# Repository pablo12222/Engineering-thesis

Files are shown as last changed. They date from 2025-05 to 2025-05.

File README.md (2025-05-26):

# Development of an electronic optimizer to control pump operation.

## Introduction

This repository contains the work and resources related to my engineering thesis titled **"Development of an electronic optimizer to control pump operation."** 

---
## Abstract 

The engineering thesis focuses on the development and construction of an electronic
(microprocessor-based) model of a setpoint controller for regulating pump performance.
The device will be implemented using a selected microcontroller with appropriately
designed input/output interfaces to interact with external devices and facilitate user
communication. The system’s operating principle can be described as follows: the
controller receives an analog 0 − 10 V signal from a regulating valve, representing the
position of the valve ball. It then compares this value with the pump’s output setpoint.
If the signal from the valve is lower than the setpoint, the device reduces the output
signal by 0.1 V at regular time intervals determined by an encoder until the target value
is reached. Conversely, if the valve ball position value exceeds the setpoint, the
controller increases the output signal by 0.1 V at the specified time intervals. The
system is equipped with three encoders for configuring operating parameters, two analog
inputs 0 − 10 V, and one analog output 0 − 10 V, ensuring precise control and
adaptation of pump performance to operational requirements. The device operates in
two modes: automatic and manual. As part of the thesis, functional tests will be
conducted using available measurement instruments and voltage generators to verify the
correct operation and compliance of the device with the design assumptions. The task is
carried out in accordance with the guidelines and for the purposes of BELIMO -
BELIMO Siłowniki S.A.

--- 

## Keywords
- transmitter,
- electronic device,
- pump control,
- microprocessor system,
- building automation.

---

## Device
This is how the developed prototype looks like:

<div style="display: flex; justify-content: center; align-items: center; gap: 10px;">
    Experimental Setup
    Experimental Result
</div>

---

## Systems hardware

Ideological diagram of the operation of the transmitter:

schemat_ideowy

---

The PCB was made with autodesk EAGLE software:


<div style="display: flex; justify-content: center; align-items: center; gap: 10px;">
    Experimental Result1
    Experimental Result2
    Experimental Result3
</div>

---

The PCB enclosure was made in Autodesk Inventor:
<div style="display: flex; justify-content: center; align-items: center; gap: 10px;">
    Experimental Result1
    Experimental Result2
    Experimental Result3
</div>

---

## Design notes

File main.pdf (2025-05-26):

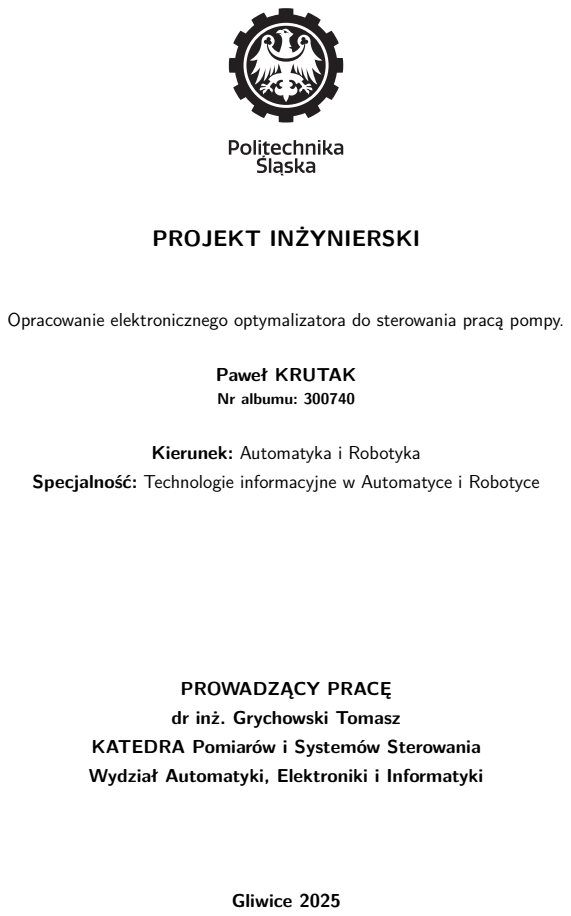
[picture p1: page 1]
PROJEKT INŻYNIERSKI; Paweł KRUTAK; Nr albumu: 300740; Gliwice 2025

Opracowanie elektronicznego optymalizatora do sterowania pracą pompy.

Kierunek: Automatyka i Robotyka

Specjalność: Technologie informacyjne w Automatyce i Robotyce

PROWADZĄCY PRACĘ
dr inż. Grychowski Tomasz

KATEDRA Pomiarów i Systemów Sterowania
Wydział Automatyki, Elektroniki i Informatyki

Opracowanie elektronicznego optymalizatora do sterowania pracą pompy.

Opracowanie elektronicznego optymalizatora do sterowania pracą pompy.

Streszczenie

Praca | inżynierska | dotyczy | opracowania | i | budowy | elektronicznego
(mikroprocesorowego) modelu zadajnika kontrolującego wydajność pompy. Urządzenie zostanie zrealizowane na bazie wybranego mikrokontrolera z zaprojektowanymi odpowiednimi interfejsami wejścia/wyjścia do współpracy z urządzeniami zewnętrznymi oraz komunikacji z użytkownikiem.
Zasadę działania systemu można opisać w następujący sposób: zadajnik odbiera sygnał analogowy 0 − 10 V z zaworu regulacyjnego reprezentujący położenie kuli zaworu. Następnie porównuje tę wartość z nastawą wyjściową pompy. W przypadku, gdy sygnał z zaworu jest mniejszy od wartości zadanej, urządzenie zmniejsza sygnał wyjściowy o 0,1 V w regularnych odstępach czasu określonych za pomocą encodera aż do osiągnięcia zadanej wartości. Analogicznie, jeśli wartość położenia kuli zaworu przekracza wartość zadaną, zadajnik zwiększa sygnał wyjściowy o 0,1 V w określonych odstępach czasu. Układ został wyposażony w trzy encodery umożliwiające konfigurację parametrów pracy, dwa wejścia analogowe 0 − 10 V oraz jedno wyjście analogowe 0 − 10 V, co zapewnia precyzyjne sterowanie i dostosowanie działania pompy do wymagań operacyjnych. Urządzenie pracuje w dwóch trybach: automatycznym oraz manualnym. W ramach pracy przeprowadzone zostaną również testy funkcjonalne z wykorzystaniem dostępnych urządzeń pomiarowych oraz zadajników napięć, mające na celu weryfikację poprawności działania i zgodności z założeniami projektowymi. Zadanie to zrealizowane jest według wytycznych i na potrzeby firmy BELIMO - BELIMO Siłowniki S.A.

Słowa kluczowe

(zadajnik, urządzenie elektroniczne, sterowanie pompą, układ mikroprocesorowy, automatyka budynkowa)

Thesis title

Development of an electronic optimizer to control pump operation.

Abstract

The engineering thesis focuses on the development and construction of an electronic (microprocessor-based) model of a setpoint controller for regulating pump performance. The device will be implemented using a selected microcontroller with appropriately designed input/output interfaces to interact with external devices and facilitate user communication. The system’s operating principle can be described as follows: the controller receives an analog 0 − 10 V signal from a regulating valve, representing the position of the valve ball. It then compares this value with the pump’s output setpoint. If the signal from the valve is lower than the setpoint, the device reduces the output signal by 0.1 V at regular time intervals determined by an encoder until the target value is reached. Conversely, if the valve ball position value exceeds the setpoint, the controller increases the output signal by 0.1 V at the specified time intervals. The system is equipped with three encoders for configuring operating parameters, two analog inputs 0 − 10 V, and one analog output 0 − 10 V, ensuring precise control and adaptation of pump performance to operational requirements. The device operates in two modes: automatic and manual. As part of the thesis, functional tests will be conducted using available measurement instruments and voltage generators to verify the correct operation and compliance of the device with the design assumptions. The task is carried out in accordance with the guidelines and for the purposes of BELIMO -BELIMO Siłowniki S.A.

Key words

(transmitter, electronic device, pump control, microprocessor system, building automation)

# Spis treści

1 Wstęp | 1
2 Opis działania zadajnika. | 4
3 Wykorzystane narzędzia pomiarowe. | 11
4 Hardware | 16

4.4.4 | Wybór Encoderów Zamiast Potencjometrów do Zadawania Wartości. 26
5 Software | 33

5.1.14 Inicjalizacja interfejsów komunikacyjnych i urządzeń peryferyjnych . 46

5.1.23 Odczyt, przetwarzanie i skalowanie napięć z pinów: VP i VN. . . . 51

6 Weryfikacja i walidacja | 57
6.2 Badanie | liniowości | przetwarzanego | napięcia | z | wejść | i | wyjścia
6.2.1 | Badanie liniowości przetwarzanego napięcia sygnału wyjściowego ze
6.2.2 | Badanie liniowości przetwarzanego napięcia sygnału z położenia kuli

6.3 Pomiary napięcia referencyjnego i rzeczywistego dla wejść zadajnika. . . . 60

6.3.2 | Pomiary napięcia referencyjnego i rzeczywistego dla wejścia z
7 Podsumowanie i wnioski | 65
Bibliografia | 68
Spis skrótów i symboli | 70
Lista dodatkowych plików, uzupełniających tekst pracy | 71
Spis rysunków | 73
Spis tabel | 74

# Rozdział 1

# Wstęp

Praca inżynierska koncentruje się na opracowaniu i budowie elektronicznego modelu zadajnika kontrolującego wydajność pompy, wykorzystującego mikrokontroler jako jednostkę obliczeniową. Celem projektu jest zbudowanie prototypu urządzenia według wytycznych i na potrzeby firmy BELIMO - BELIMO Siłowniki S.A. , który może być zastosowany do pracy z rzeczywistymi urządzeniami przemysłowymi. Kluczowym zadaniem opracowanego urządzenia jest precyzyjna regulacja parametrów pracy pompy, co pozwoli na optymalizację jej wydajności i dostosowanie do zmiennych warunków operacyjnych. Przez optymalizację rozumiemy dynamiczne dostosowanie zadajnika do zmieniających się parametrów wejściowych. Przez takie podejście uzyskujemy poprawę efektywności i wydajności pracy pompy. Niniejsza praca składa się z siedmiu rozdziałów, w których szczegółowo opisano proces projektowania, implementacji oraz testowania elektronicznego optymalizatora do sterowania pracą pompy.
Rozdział pierwszy, Wstęp, przedstawia cel projektu, znaczenie podjętego tematu oraz spodziewane korzyści wynikające z realizacji projektu. Wyjaśniono również kontekst przemysłowy, w którym może zostać zastosowany zaprojektowany zadajnik.
W rozdziale drugim, Opis działania zadajnika, omówiono: zastosowanie i uzasadnienie budowy zadajnika, przykład konkretnej instalacji, wymagania sprzętowe oraz urządzenia, z którymi zadajnik będzie współpracował. Szczegółowo zaprezentowano zasadę działania systemu, uwzględniając różne scenariusze pracy w zależności od dostępności sygnałów sterujących. Zadajnik będzie wyposażony w następujące wejścia i wyjście.
Wejścia: dwa wejścia analogowe 0 − 10 V (jedno z pompy, drugie z zaworu EV). Wyjście: jedno wyjście analogowe 0 − 10 V (do sterowania pompy).
Nastawy: encoder z wartościami od 0 do 10 V odpowiadający wartości wyjściowej. Encoder z wartościami 0 − 10 V w przypadku braku informacji z systemu zarządzania budynkiem "BMS"(ang. Building Management System), gdzie sygnał pochodzi ze sterownika PLC (ang. Programmable Logic Controller). Podsystemu automatyki budynkowej, który wypracował wyjście na podstawie stanu obiektu i przesłał je do

Paweł Krutak

urządzenia w postaci wartości analogowej w standardowym zakresie 0 − 10 V oraz encoder do ustawiania czasu. Zadajnik pobiera informacje z zaworu regulacyjnego, który wysyła sygnał analogowy 0 − 10 V, reprezentujący położenie kuli zaworu. Na podstawie tego sygnału zadajnik porównuje otrzymaną wartość z wartością wyjściową. Jeśli sygnał z zaworu jest mniejszy od wartości wyjściowej, zadajnik zmniejsza sygnał wyjściowy do pompy o 0,1 V w ustalonych odstępach czasu, aż do osiągnięcia wartości zadanej. Analogicznie, jeśli wartość położenia kuli zaworu jest większa od wyjściowej, zadajnik zwiększa sygnał wyjściowy pompy o 0,1 V w tych samych odstępach czasu. Zawór Energy Valve [5] generuje sygnał wyjściowy 0 − 10 V, który można skonfigurować do przesyłania informacji o położeniu kuli zaworu. Zadajnik precyzuje pracę pompy na podstawie stopnia otwarcia kuli zaworu, dążąc do utrzymania pożądanej pracy instalacji na podstawie wartości wejściowej. W przypadku braku sygnału z BMS (Building Management System), zadajnik wykorzystuje ustawioną wartość początkową obrotów pompy jako wartość domyślną. W sytuacji, gdy sygnał z BMS jest dostępny, zadajnik musi uwzględnić ten sygnał jako nadrzędny, co oznacza, że wszelkie inne operacje są przerywane w przypadku zmiany sygnału z BMS. Przy założeniu braku sygnału z BMS, początkowa nastawa obrotów pompy ustawiona jest na 100%. Jeśli zawór Belimo wskazuje położenie kuli na 30% (3 V), zadajnik co ustawioną przez użytkownika nastawę czasu 5, 15, 30, 45, 60 sekund zmniejsza sygnał wyjściowy do pompy o 0,1 V, dążąc do osiągnięcia 30% obrotów pompy. Proces ten trwa do momentu, aż sygnał z zaworu nie osiągnie zadanej wartości, po czym zadajnik utrzymuje odpowiednie obroty pompy, do momentu zmiany sygnału zadanego. Na końcu tego rozdziału opisana została instrukcja obsługi dla użytkownika elektornicznego optymalizatora.

Rozdział trzeci, Wykorzystane narzędzia pomiarowe, zawiera opis przyrządów używanych podczas testowania, takich jak zasilacz laboratoryjny oraz multimetry, ze szczególnym uwzględnieniem ich parametrów i zastosowania.

Rozdział czwarty, Hardware, skupia się na sprzętowej części projektu. Zawarto w nim opis komponentów wykorzystanych w zadajniku, w tym mikrokontrolera ESP32, modułu RTC, wyświetlacza OLED oraz innych elementów elektronicznych. Szczególną uwagę poświęcono projektowaniu układu elektronicznego, w tym schematu połączeń, płytki drukowanej oraz obudowy urządzenia, co pozwala na pełne zrozumienie poszczególnych etapów realizacji projektu. Dodatkowo, omówiono kompatybilność wybranych komponentów z mikrokontrolerem oraz pozostałymi elementami układu, co pozwoli na eliminację potencjalnych problemów w fazie implementacji. Rozdział czwarty dostarcza kompleksowego spojrzenia na projektowanie i implementację warstwy sprzętowej, podkreślając znaczenie synergii pomiędzy komponentami elektronicznymi a oprogramowaniem sterującym. Opisane procesy projektowe i techniczne decyzje stanowią solidną podstawę dla realizacji funkcjonalnego i niezawodnego zadajnika, odpowiadającego wymaganiom założonym na etapie planowania projektu.

Rozdział 1. Wstęp

Rozdział piąty, Software, obejmuje szczegółowy opis oprogramowania zadajnika, napisanego w języku C z wykorzystaniem środowiska Arduino IDE. Oprogramowanie stanowi kluczowy element projektu, umożliwiający pełną kontrolę nad sprzętowymi komponentami urządzenia oraz realizację jego funkcji użytkowych. Początkowo przedstawiono strukturę programu, w tym podział na moduły oraz funkcje realizujące konkretne zadania. Omówiono główne bloki kodu, takie jak inicjalizacja urządzeń peryferyjnych, obsługa wejść/wyjść cyfrowych i analogowych, a także implementacje kluczowych algorytmów sterujących. Szczególną uwagę poświęcono usprawnieniu kodu, aby zapewnić jego efektywność i zgodność z ograniczeniami zasobów mikrokontrolera. Dalsza część rozdziału zostanie poświęcona omówieniu zastosowanych bibliotek, takich jak Wire.h, U8g2lib.h, RTClib.h oraz innych, które wspierają komunikację z urządzeniami peryferyjnymi. Szczegółowo opisane zostaną sposoby wykorzystania funkcji tych bibliotek do realizacji takich zadań, jak sterowanie wyświetlaczem OLED, synchronizacja czasu z modułem RTC, czy obsługa interfejsu I²C. Wyjaśnione zostaną mechanizmy, dzięki którym biblioteki te zostały zaadaptowane do specyficznych wymagań projektu. Ponadto omówione zostaną metody obsługi zdarzeń, w tym przerwania oraz reakcje na sygnały wejściowe generowane przez przyciski. Szczególną uwagę poświęcono implementacji różnych trybów pracy urządzenia, w tym automatycznego oraz ręcznego sterowania. W końcowej części rozdziału zostaną omówione metody testowania i weryfikacji poprawności działania kodu. Opisane zostaną techniki debugowania oraz sposoby wykrywania i eliminacji potencjalnych błędów. Rozdział ten ma na celu dostarczenie pełnego obrazu procesu tworzenia i implementacji oprogramowania, które zapewnia niezawodne i efektywne działanie zadajnika.
Rozdział szósty, Weryfikacja i walidacja, prezentuje fazę testowania, podczas której zostanie sprawdzona poprawność działania zadajnika z wykorzystaniem dostępnych urządzeń pomiarowych oraz zadajników napięć. Testy te mają na celu potwierdzenie, że zadajnik działa zgodnie z założeniami i jest w stanie skutecznie zarządzać pracą pompy w różnych scenariuszach operacyjnych. W dalszych częściach pracy zostaną przedstawione szczegółowe opisy poszczególnych funkcjonalności, wyniki testów oraz analiza działania zadajnika w kontekście rzeczywistych aplikacji przemysłowych.
Ostatni rozdział, Podsumowanie i wnioski, podsumowuje efekty pracy, ocenia stopień realizacji założonych celów oraz wskazuje potencjalne kierunki rozwoju projektu.

# Rozdział 2

Opis działania zadajnika.

Współczesne systemy automatyzacji wymagają coraz bardziej zaawansowanych narzędzi umożliwiających precyzyjne sterowanie pracą urządzeń, w tym pomp
wykorzystywanych | w | różnorodnych | instalacjach | przemysłowych, | budynkowych
i technologicznych. Zadania te obejmują dynamiczne dostosowywanie parametrów pracy do zmieniających się warunków operacyjnych oraz potrzeb użytkowników.
Rozdział drugi pracy inżynierskiej koncentruje się na szczegółowym opisie działania projektowanego zadajnika, jego funkcjonalności oraz współpracy z elementami systemu. Zadania realizowane przez zadajnik obejmują precyzyjną regulację pracy pompy w instalacjach technicznych, takich jak systemy HVAC, budynki komercyjne, instalacje przemysłowe oraz systemy chłodzenia serwerowni.
W kolejnych podrozdziałach przedstawiono szerokie zastosowania zadajnika, a także omówiono przykłady konkretnych instalacji, w których może być on wykorzystany.
Zaprezentowano | także | szczegółowe | wymagania | sprzętowe, | opis | urządzeń
współpracujących z zadajnikiem oraz dokładny opis zasad jego działania.

2.1 Zastosowania i uzasadnienie budowy zadajnika.

Projektowany zadajnik znajduje szerokie zastosowanie w systemach automatyzacji, które wymagają precyzyjnego sterowania pracą pomp oraz usprawnienia przepływu medium. Przykłady takich instalacji obejmują:

- Systemy HVAC (Heating, Ventilation, Air Conditioning): Zadaniem zadajnika w takich systemach jest dynamiczne dostosowanie pracy pomp obiegowych do aktualnych warunków eksploatacyjnych, takich jak zmienne zapotrzebowanie na ciepło lub chłód. Dzięki precyzyjnej regulacji przepływu medium możliwe jest zwiększenie efektywności energetycznej całego systemu, co prowadzi do obniżenia kosztów eksploatacji oraz zmniejszenia emisji CO2.
- Budynki komercyjne i użyteczności publicznej: W dużych budynkach,

Rozdział 2. Opis działania zadajnika.

takich jak biurowce, hotele czy szpitale, utrzymanie stabilnych parametrów pracy układów cyrkulacyjnych jest kluczowe dla komfortu użytkowników oraz wydajności systemu. Zadania realizowane przez zadajnik, takie jak dostosowanie prędkości pomp do sygnałów wejściowych z systemu zarządzania budynkiem (BMS), zapewniają niezawodność i efektywność instalacji.

- Instalacje | przemysłowe: | W | procesach | technologicznych | wymagających
precyzyjnej regulacji przepływu medium, np. w układach chłodzenia maszyn lub urządzeń, zadajnik umożliwia sterowanie pracą pompy, co przekłada się na większą kontrolę nad procesami oraz oszczędności energetyczne.
- Systemy chłodzenia serwerowni: W serwerowniach precyzyjne sterowanie temperaturą jest kluczowe dla zapewnienia ciągłości pracy sprzętu. Zadajnik umożliwia regulację przepływu medium chłodzącego w zależności od obciążenia systemu, co pozwala na efektywne zarządzanie temperaturą.

Głównym celem projektu zadajnika jest zwiększenie efektywności i elastyczności zarządzania pracą pomp w różnych instalacjach. Współczesne systemy HVAC oraz instalacje przemysłowe wymagają coraz bardziej zaawansowanych metod regulacji, które pozwalają na dynamiczne dostosowywanie parametrów pracy do zmieniających się warunków.

2.1.1 Przykład konkretnej instalacji.

Projektowany zadajnik może być zastosowany w instalacji grzewczej nowoczesnego budynku biurowego, w którym system HVAC (ogrzewanie, wentylacja i klimatyzacja) wykorzystuje pompy obiegowe do cyrkulacji medium grzewczego.
W tej instalacji zastosowano:
- Pompy obiegowe Wilo-Yonos ECO 25/1-5, sterowane napięciem 0 − 10 V, które dynamicznie dostosowują prędkość przepływu wody w zależności od zapotrzebowania na ciepło w różnych strefach budynku.
- Zawory Belimo Energy Valve™, które monitorują i kontrolują przepływ medium oraz przekazują sygnały o położeniu kuli zaworu (stopnia otwarcia). Położenie kuli zaworu jest kluczowym parametrem, który pozwala na precyzyjne określenie bieżącego zapotrzebowania na przepływ medium w danej strefie budynku.
- System zarządzania budynkiem (BMS), który zbiera dane o zapotrzebowaniu na energię cieplną w poszczególnych strefach obiektu i przesyła je do zadajnika jako sygnały wejściowe.

Paweł Krutak

W praktyce zadajniki odczytują sygnały z zaworu regulacyjnego oraz z systemu BMS. Na podstawie informacji o położeniu kuli zaworu oraz sygnału z BMS, zadajniki dynamicznie regulują prędkość obrotową pomp. Dzięki temu każda strefa budynku otrzymuje dokładnie tyle energii cieplnej, ile potrzebuje, co minimalizuje straty energetyczne i obniża koszty eksploatacji.

Przykład zastosowania: W budynku o powierzchni 10 000 m², podzielonym na kilka stref grzewczych (np. biura, sale konferencyjne, pomieszczenia techniczne), zadajniki umożliwiają regulację pracy pomp w taki sposób, aby dopasować przepływ medium grzewczego do zapotrzebowania każdej strefy. Na przykład:

- W godzinach pracy biur (8:00–18:00) system, bazując na informacji o położeniu kuli zaworu, zwiększa przepływ medium do stref intensywnie użytkowanych.
- W godzinach nocnych system BMS, przy wsparciu zadajnika, redukuje przepływ do minimalnego poziomu, pozwalając jedynie na utrzymanie temperatury ochronnej (np. 15°C).

Dzięki wykorzystaniu informacji o położeniu kuli zaworu oraz sygnałów z systemu BMS, takie rozwiązanie pozwala na wydajniejszą pracę systemu grzewczego, zmniejszenie zużycia energii o 20–30% oraz zwiększenie komfortu użytkowników budynku.

2.2 Wymagania sprzętowe do projektu.

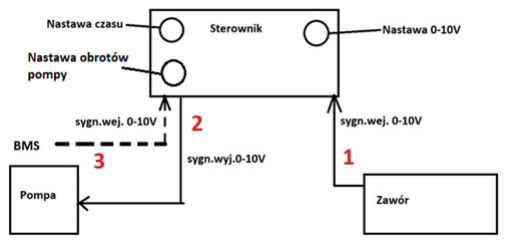
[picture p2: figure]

Rysunek 2.1: Ideowy schemat działania zadajnika (rysunek od "zleceniodawcy").

Zaprojektowany zadajnik ma wykorzystywać mikrokontroler jako centralną jednostkę obliczeniową, która ma odczytywać wejścia i w odpowiedni sposób wysterowywać
wyjścia. | Na | rysunku | 2.1 | przedstawiono | ideowy | schemat | działania | układu.
Mikrokontroler odczytuje sygnały analogowe z zakresu 0 − 10 V. Jeden z nich przekazuje

Rozdział 2. Opis działania zadajnika.

informacje o położeniu kuli zaworu EV, a drugi dostarcza dane o prędkości obrotowej silnika pompy - sygnał z systemu zarządzania budynkiem "BMS"(ang. Building Management System). Wyjście przekazuje sygnał ciągły 0 − 10 V, który steruje pompą. Na rysunku 2.1 przedstawiono trzy encodery umożliwiające ustalenie nastaw. Pierwszy z nich to nastawa czasu, w którym użytkownik może wybrać wartości z przedziału 5, 15, 30, 45, 60 sekund. Drugi encoder jest do ustawienia obrotów pompy w przypadku braku sygnału wejściowego z BMS’u - nastawa wartości 0 − 10 V z krokiem 0.1 V. Ostatni z kolei ma działać tak samo jak drugi encoder, ale służy do ustawienia wartości wyjściowej do sterowania pompą.

## 2.3 Opis urządzeń do których zadajnik ma zostać

podpięty.

### Pompa obiegowa Wilo-Yonos ECO 25/1-5 BMS z sygnałem 0-

10V.

Rysunek 2.2: Opis sygnałów i wyprowadzeń pompy obiegowej Wilo-Yonos ECO 25 [22].

Pompa | obiegowa | Wilo-Yonos | ECO | 25/1-5 | to | wydajne | urządzenie
wykorzystywane w systemach grzewczych i chłodniczych, które pracuje w zakresie napięcia sterującego 0 − 10 V. Posiada zdolność dostosowywania swoich obrotów w zależności od sygnału sterującego, co pozwala na polepszenie pracy całego systemu. Sygnał sterujący można przesyłać do pompy za pomocą dedykowanego wejścia - rysunek 2.2, co umożliwia jej integrację z systemami automatyki budynkowej. Masa sygnału (GND) oraz zasilanie pompy muszą być poprawnie podłączone, aby zapewnić właściwą komunikację i stabilną pracę urządzenia [22].
Sygnał 0 − 10 V w technologii automatyki budynkowej (Building Management System, BMS) jest standardowym sygnałem analogowym, powszechnie stosowanym w systemach automatyki przemysłowej i budynkowej. W praktyce sygnał ten może być generowany przez sterownik PLC (ang. Programmable Logic Controller) będący częścią podsystemu automatyki budynkowej. Sterownik, na podstawie analizy stanu obiektu (np. odczytu temperatury, przepływu czy zapotrzebowania na energię cieplną), generuje sygnał wyjściowy i przesyła go do naszego urządzenia w postaci standardowego sygnału

Paweł Krutak

analogowego 0 − 10 V. Taki sygnał może być wykorzystany do sterowania parametrami pracy urządzeń, takimi jak prędkość obrotowa pompy czy przepływ medium. Dzięki temu możliwe jest precyzyjne zarządzanie systemami grzewczymi i chłodniczymi, co prowadzi do zwiększenia efektywności energetycznej oraz redukcji kosztów eksploatacji.

Zawór Belimo Energy Valve™.

Zawór Belimo Energy Valve™ to zaawansowane urządzenie służące do zarządzania przepływem medium w systemach HVAC. Jest wyposażony w interfejs sygnału 0 − 10 V co umożliwia monitorowanie i kontrolę położenia kuli zaworu (stopnia otwarcia). Funkcjonalność ta pozwala na precyzyjne sterowanie wydajnością instalacji, zwiększając jej efektywność. Energy Valve (EV) pozwala także na wybór rodzaju przesyłanej informacji. Jednym z najistotniejszych parametrów jest pozycja kuli zaworu, która może służyć za podstawę do regulacji pracy pompy. Informację o położeniu kuli zaworu otrzymujemy z pomarańczowego oraz białego przewodu przedstawionego na rysunku 2.3, Urządzenie wspiera działania usprawniające, dzięki czemu możliwe jest utrzymywanie odpowiednich parametrów instalacji przy minimalnym zużyciu energii [5].

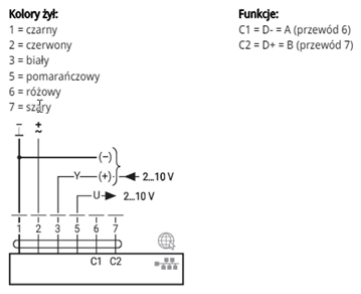
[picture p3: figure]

Rysunek 2.3: Wyprowadzenia sygnałów z zaworu Belimo Energy Valve™ [5].

2.4 Dokładny opis działania systemu.

System sterowania pompą na podstawie informacji z zaworu oparty jest na mikrokontrolerze ESP32 i umożliwia dynamiczne dostosowywanie pracy instalacji w zależności od aktualnych warunków oraz preferencji użytkownika. Główne zadanie

Rozdział 2. Opis działania zadajnika.

systemu polega na regulacji prędkości pompy na podstawie sygnałów napięciowych 0 − 10 V pochodzących z zaworu regulacyjnego i systemu zarządzania budynkiem (BMS). System działa w dwóch trybach: automatycznym i manualnym. W trybie automatycznym zadajnik analizuje sygnał z położenia kuli zaworu (EV), porównując go z aktualną wartością wyjściową co ustawiony interwał czasowy, na przykład 8 V to odpowiada 80% otwarcia zaworu. Przez użytkownika określany jest interwał czasowy, ustawiony za pomocą encodera z przedziału 5, 15, 30, 45, 60 sekund. Zadajnik dostosowuje napięcie wyjściowe dla pompy, zwiększając lub zmniejszając je o 0,1 V, aby osiągnąć zadany poziom. W przypadku dostępności sygnału z BMS system bezpośrednio przekazując wartość sterującą z BMS do pompy. Tryb manualny pozwala użytkownikowi na bezpośrednie ustawienie napięcia wyjściowego za pomocą enkodera, umożliwiając pełną kontrolę nad pracą pompy. Interfejs użytkownika obejmuje wyświetlacz OLED, na którym prezentowane są informacje o aktualnym czasie, trybie pracy, trybie pracy BMS (w przypadku braku wartości wejściowej z BMS użytkownik może zmienić tryb i ustawić priorytetową wartość za pomocą enkodera), wartości wejściowych z EV i BMS, napięciu wyjściowym dla pompy oraz aktualnych nastawach. Dodatkowo diody LED sygnalizują aktywność pompy, stan zaworu oraz obecność sygnału z BMS. W przypadku braku sygnału wejściowego z BMS w chwili startu zadajnik startuje z wartości wyjściowej dla pompy równej 10 V.

2.5 | Instrukacja | obsługi | elektronicznego
| optymalizatora.

Elektroniczny optymalizator jest urządzeniem przeznaczonym do precyzyjnej regulacji pracy pomp w systemach HVAC oraz innych instalacjach wymagających dynamicznego sterowania przepływem medium. Aby rozpocząć pracę, należy podłączyć urządzenie do źródła zasilania 12 V oraz upewnić się, że sygnały z zaworu regulacyjnego EV i systemu BMS są poprawnie podłączone do dedykowanych wejść. Po uruchomieniu urządzenia domyślnie aktywowany jest tryb automatyczny, w którym elektroniczny optymalizator analizuje sygnały napięciowe 0 − 10 V z wejść i dostosowuje napięcie wyjściowe sterujące pompą. Interwał czasowy regulacji można ustawić za pomocą obrotowego encodera, wybierając wartość z przedziału {5, 15, 30, 45, 60} sekund, a wybrany interwał jest prezentowany na wyświetlaczu OLED.

W trybie automatycznym optymalizator priorytetowo wykorzystuje sygnał z systemu BMS, o ile jest dostępny, przekazując bezpośrednio wartość sterującą do pompy. W przypadku braku sygnału z BMS regulacja odbywa się na podstawie pozycji kuli zaworu EV, którą urządzenie porównuje z aktualnym napięciem wyjściowym i koryguje o 0.1 V co zadany interwał czasowy. Istnieje jednak możliwość zmiany źródła wartości

Paweł Krutak

wejściowej w przypadku braku sygnału z BMS. Użytkownik może przełączyć tryb wejściowy na wartość zadaną za pomocą encodera nastawy BMS. W tym trybie encoder pełni funkcję ustawienia priorytetowej wartości, która będzie wykorzystywana do sterowania pompą. Przełączanie trybu źródła sygnału odbywa się za pomocą wbudowanego przycisku encodera.
W trybie manualnym użytkownik może ręcznie ustawić napięcie wyjściowe za pomocą encodera, a jego wartość jest na bieżąco wyświetlana na ekranie OLED. Interfejs użytkownika dostarcza kluczowych informacji o stanie systemu, w tym aktualnego czasu, trybu pracy (automatyczny/manualny), napięć z wejść EV i BMS, napięcia wyjściowego oraz źródła danych wejściowych (BMS_WE lub BMS_ENC). Dodatkowo diody LED sygnalizują aktywność napięcia wyjściowego, obecność sygnału z BMS oraz sygnału z zaworu EV, co umożliwia szybkie monitorowanie stanu urządzenia. W przypadku braku sygnału z BMS podczas uruchamiania systemu, optymalizator rozpoczyna pracę z maksymalnym napięciem wyjściowym 10 V, co zapewnia pełną moc pompy do czasu ustabilizowania parametrów. Regularne odczyty i przetwarzanie sygnałów są realizowane w sposób ciągły, co gwarantuje płynną pracę urządzenia oraz wysoką precyzję regulacji. W razie problemów, takich jak brak wyświetlania na OLED, nieaktywne diody lub nieprawidłowe działanie encodera, należy sprawdzić poprawność połączeń, wartości sygnałów wejściowych oraz stan techniczny podzespołów.

# Rozdział 3

Wykorzystane narzędzia pomiarowe.

Celem niniejszego rozdziału jest przedstawienie narzędzi pomiarowych, które zostały wykorzystane w trakcie realizacji projektu, zarówno podczas pisania oprogramowania dla mikrokontrolera, jak i w procesie badania liniowości zaprojektowanego układu. Opisano tutaj urządzenia, które umożliwiły precyzyjne pomiary kluczowych parametrów systemu, takich jak napięcia, rezystancje oraz inne właściwości elektryczne.

Przeprowadzenie precyzyjnych pomiarów oraz analiza uzyskanych wyników stanowiły kluczowy element weryfikacji poprawności działania zaprojektowanego zadajnika oraz oceny zgodności jego parametrów z założeniami projektowymi. W rozdziale omówiono zasilacz laboratoryjny, który służył jako symulator sygnałów wejściowych, oraz dwa multimetry cyfrowe, wykorzystywane do precyzyjnych pomiarów napięć i rezystancji.

Przedstawienie parametrów technicznych i zakresów działania użytych narzędzi pozwala podkreślić ich rolę w procesie projektowania i testowania układu sterowania, a także zapewnia wiarygodność uzyskanych wyników.

3.1 Zasilacz laboratoryjny.

Zasilacz laboratoryjny DF173005C [13], przedstawiony na rysunku 3.1, to
wszechstronne | urządzenie | przeznaczone | do | precyzyjnego | zasilania | układów
elektronicznych. Znajduje zastosowanie w laboratoriach, pracach serwisowych oraz procesach prototypowania.

### Dokładność napięcia

Dokładność napięcia wyjściowego zasilacza wynosi:

±(1% wartości ustawionej + 2 cyfry),

Paweł Krutak

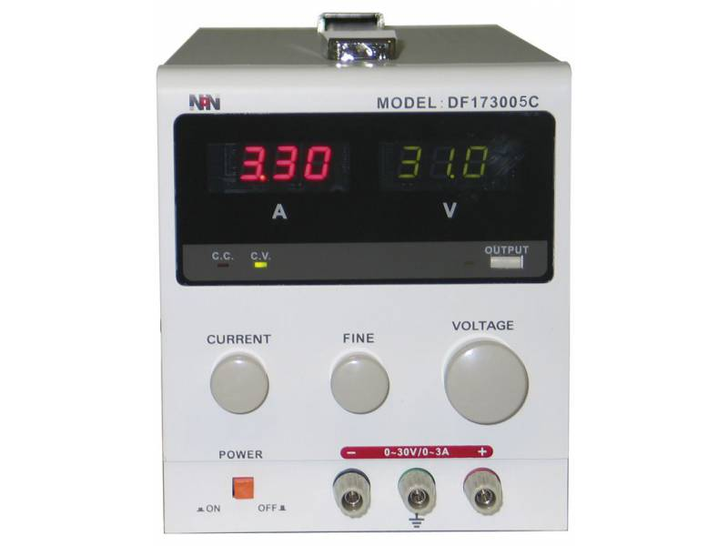
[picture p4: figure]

Rysunek 3.1: Zasilacz laboratoryjny DF173005C NDN – 30V, 5A. Zdjęcie ze strony sklepu ndn.com.pl [13].

co gwarantuje stabilne i precyzyjne zasilanie układów wymagających pewnej dokładności [13].

### Zakres pracy

Zasilacz umożliwia regulację napięcia w zakresie od 0 V do 30 V, z minimalnym tętnieniem wynoszącym ≤ 1 mVrms (dla zakresu częstotliwości od 5 Hz do 1 MHz). Tętnienia i szumy są minimalne, co zapewnia stabilność napięcia wyjściowego, szczególnie w układach czułych na zakłócenia [13].

Zastosowanie zasilacza w projekcie.

Zasilacz DF173005C został wykorzystany w projekcie jako źródło symulowanych sygnałów wejściowych, reprezentujących informacje o położeniu kuli zaworu EV oraz wartości sygnału BMS w zakresie 0 − 10 V oraz dla wejścia sygnału z BMS’u, który też pracuje w tym zakresie.

## 3.2 Wykorzystane multimetry:

Wykorzystane w projekcie multimetry służyły do pomiarów takich jak: pomiar rezystancji rezystorów, sprawdzenie liniowości dzielnika napięcia dla dobranych rezystorów, badanie liniowości wzmacniacza operacyjnego dla obliczonych parametrów, sprawdzenie liniowości dla wejść układu oraz badanie liniowości wyjścia zadajnika.

Rozdział 3. Wykorzystane narzędzia pomiarowe.

### 3.2.1 Multimetr Sonel

Multimetr cyfrowy Sonel CMM-10 [12], przedstawiony na rysunku 3.2, to zaawansowane narzędzie pomiarowe, umożliwiające precyzyjne pomiary napięcia stałego
oraz | rezystancji. | Jego | wszechstronność | sprawia, | że | znajduje | zastosowanie
w różnorodnych pracach laboratoryjnych i inżynierskich.

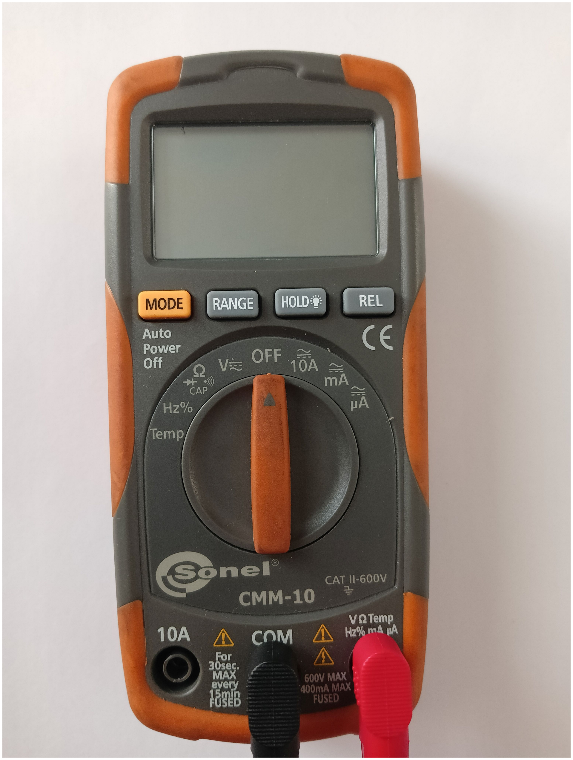
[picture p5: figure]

Rysunek 3.2: Multimetr Sonel CMM-10.

Multimetr w projekcie był wykorzystywany jako woltomierz do pomiaru wartości napięcia prądu stałego, oraz omomierz - pomiar rezystancji. Poniżej znajduje się opis dokładności miernika dla pomiaru tych dwóch wartości.

Pomiar napięcia stałego (DC)

Multimetr oferuje zakres pomiaru napięcia stałego do 600 V z dokładnością wynoszącą:

±(0, 5% wartości mierzonej + 2 cyfry).

Rozdzielczość pomiaru wynosi od 0,1 mV, co umożliwia dokładne analizy w szerokim zakresie pomiarowym [12].

Paweł Krutak

### Pomiar rezystancji

Urządzenie pozwala na pomiar rezystancji do 40,00 MW z dokładnością:

±(1, 0% wartości mierzonej + 2 cyfry).

Rozdzielczość wynosi od 0,1 W, co zapewnia precyzyjne wyniki nawet w przypadku dużych wartości rezystancji [12].

Multimetr NEO.

Multimetr cyfrowy NEO 94-001 [18] pokazany na rysunku 3.3, został wykorzystany w projekcie wyłącznie do pomiarów napięcia prądu stałego. Dlatego poniżej zostały opisane dane dotyczące zakresów, rozdzielczości oraz dokładności, jedynie dla woltomierza prądu stałego.

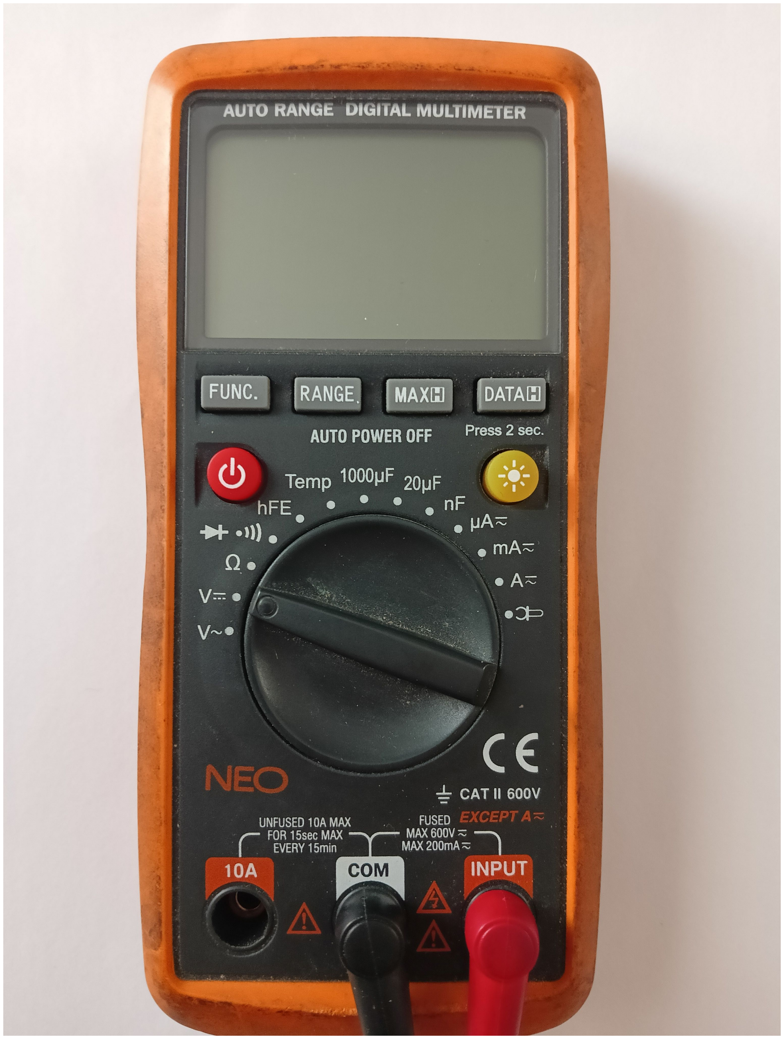
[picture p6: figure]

Rysunek 3.3: Multimetr NEO 94-001.

Zakresy pomiarowe [18]

- 200 mV z rozdzielczością 0,1 mV,
- 2 V z rozdzielczością 0,001 V,
- 20 V z rozdzielczością 0,01 V,
- 200 V z rozdzielczością 0,1 V,

Rozdział 3. Wykorzystane narzędzia pomiarowe.

- 600 V z rozdzielczością 1 V.

Dokładność pomiarów [18]

- ±(0, 8% wartości mierzonej + 5 cyfr) dla zakresów do 200 V,
- ±(1, 0% wartości mierzonej + 5 cyfr) dla zakresu 600 V.

Impedancja wejściowa

Multimetr charakteryzuje się wysoką impedancją wejściową wynoszącą 10 MΩ, co minimalizuje wpływ miernika na badany obwód [18].

# Rozdział 4

# Hardware

W niniejszym rozdziale przedstawiono szczegółowy opis komponentów sprzętowych wykorzystanych w projekcie, proces projektowania płytki drukowanej (PCB) oraz wykonania obudowy urządzenia. Celem rozdziału jest przedstawienie kluczowych decyzji projektowych, które zadecydowały o funkcjonalności i niezawodności systemu sterowania pompą obiegów.
Omówione zostaną najważniejsze elementy układu, takie jak mikrokontroler ESP32, moduł czasu rzeczywistego RTC DS1307, wzmacniacz operacyjny LM358P oraz przetwornica DC-DC MP2315, wraz z uzasadnieniem ich wyboru oraz opisem ich roli w projekcie. Ponadto, szczególną uwagę poświęcono opisowi układów wspomagających, takich jak rezystory, kondensatory oraz encodery obrotowe, które umożliwiają
precyzyjne | przetwarzanie | sygnałów | wejściowych | i | sterowanie | urządzeniami
wykonawczymi.
Dalsza część rozdziału skupia się na procesie projektowania płytki PCB, który obejmował rozmieszczenie komponentów, dobór odpowiednich szerokości ścieżek. W ostatniej części rozdziału zaprezentowano projekt obudowy, której konstrukcja
została | dostosowana | do | specyfikacji | technicznych | urządzenia | i | wykonana
z wykorzystaniem technologii druku 3D. Szczegółowe omówienie tych aspektów pozwala na pełne zrozumienie procesu tworzenia sprzętu oraz jego integracji z oprogramowaniem, co jest kluczowe dla osiągnięcia założonej funkcjonalności systemu.

## 4.1 Schemat połączeń

Przy projektowaniu układu kluczowym krokiem było stworzenie szczegółowego schematu połączeń, który stanowił podstawę do zamówienia potrzebnych elementów, zaprojektowania płytki PCB oraz zaplanowania montażu. Poniższy rysunek 4.1 prezentuje schemat połączeń komponentów zadajnika zaprojektowany w programie EAGLE firmy Autodesk [4].

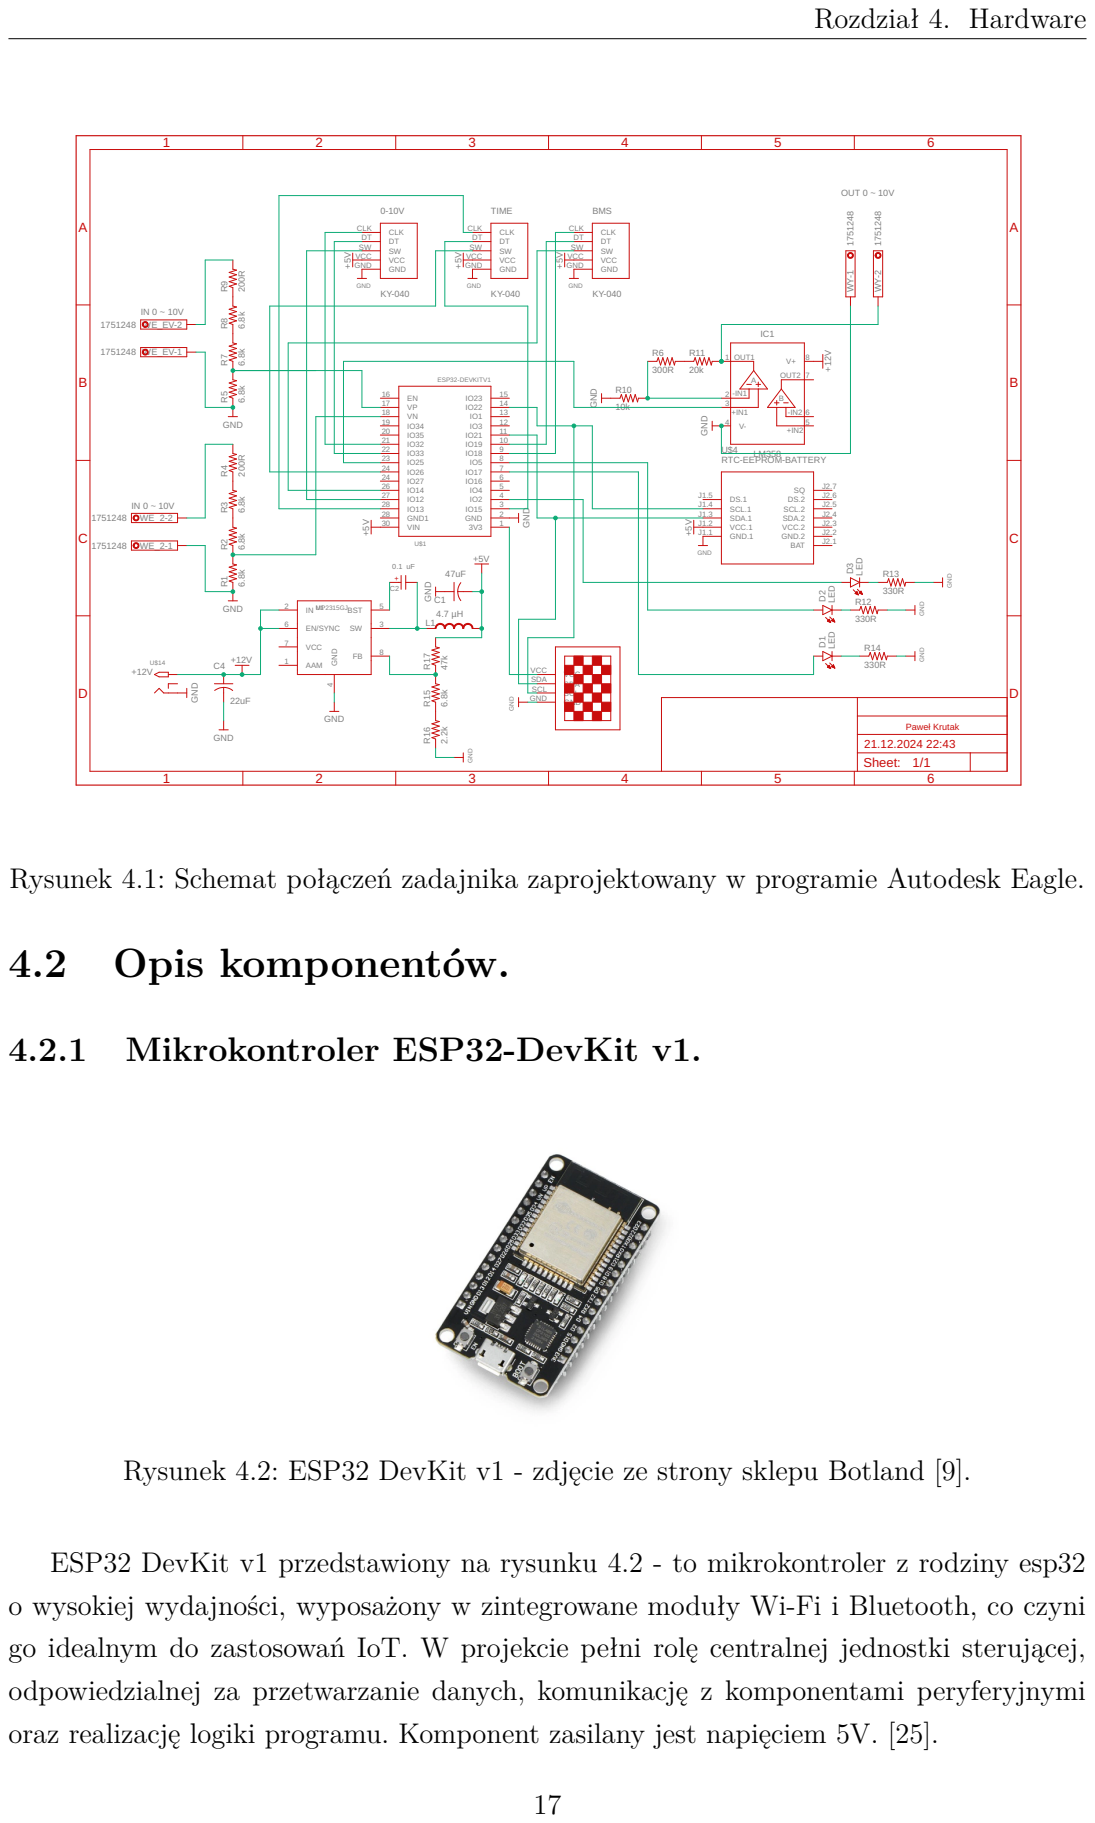
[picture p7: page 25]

OUT 0 ~ 10V

22 | 9
23 | 8 | RTC-EEPROM-BATTERY

Rysunek 4.1: Schemat połączeń zadajnika zaprojektowany w programie Autodesk Eagle.

Rysunek 4.2: ESP32 DevKit v1 - zdjęcie ze strony sklepu Botland [9].

ESP32 DevKit v1 przedstawiony na rysunku 4.2 - to mikrokontroler z rodziny esp32
o wysokiej wydajności, wyposażony w zintegrowane moduły Wi-Fi i Bluetooth, co czyni
go idealnym do zastosowań IoT. W projekcie pełni rolę centralnej jednostki sterującej,
odpowiedzialnej za przetwarzanie danych, komunikację z komponentami peryferyjnymi
oraz realizację logiki programu. Komponent zasilany jest napięciem 5V. [25].

Paweł Krutak

4.2.2 Moduł RTC DS1307 z pamięcią EEPROM 24C32.

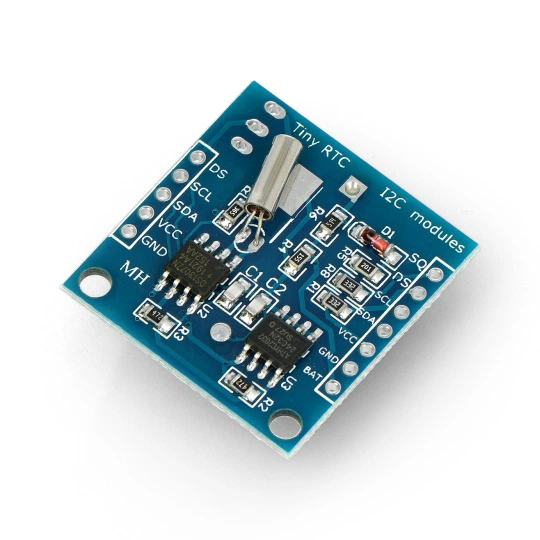
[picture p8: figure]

Rysunek 4.3: Moduł RTC DS1307 z pamięcią EEPROM 24C32 - zdjęcie ze strony sklepu Botland [20].

Moduł RTC DS1307 - rysunek 4.3 - umożliwia precyzyjne odmierzanie czasu i daty, niezależnie od zasilania, dzięki baterii podtrzymującej. Moduł jest istotny w projekcie aby, móc sterować nastawą czasu. Komunikacja z mikrokontrolerem odbywa się za pomocą interfejsu I²C. Napięcie zasilania tego elementu to 5V [20].

4.2.3 Wyświetlacz OLED 1.3"(I²C).

Rysunek 4.4: Wyświetlacz OLED - zdjęcie ze strony sklepu Botland [21].

Wyświetlacz graficzny OLED o przekątnej 1.3 cala i rozdzielczości 128x64 pikseli pokazany na rysunku 4.4 - służy do wizualizacji informacji systemowych wyświetlanych na ekranie OLED. Komunikacja z mikrokontrolerem odbywa się poprzez protokół I²C. Zasilany jest napięciem z zakresu 3.3 − 5 V. [21].

4.2.4 Encoder obrotowy KY-040.

KY-040 to encoder obrotowy, rysunek 4.5, który umożliwia użytkownikowi interakcję z systemem poprzez obrót (ustawienie nastaw) oraz nacisk (zmiana trybów). Pozwala na detekcję kierunku obrotu i precyzyjne zliczanie impulsów [14]. Jest zasilany napięciem 5V.

Rozdział 4. Hardware

Rysunek 4.5: Encoder obrotowy KY-040 - zdjęcie ze strony sklepu Botland [7].

### 4.2.5 Przetwornica DC-DC MP2315

MP2315 to przetwornik typu buck, zdolny do konwersji napięcia wejściowego (12 V) na stabilizowane napięcie wyjściowe (5 V). Jego wysoka sprawność energetyczna pozwala na minimalizację strat mocy i nie duże wydzielanie ciepła, co czyni go odpowiednim do zasilania układów elektronicznych [26].

### 4.2.6 Wzmacniacz operacyjny LM358P

LM358P to podwójny wzmacniacz operacyjny o niskim poborze mocy, zdolny do pracy z pojedynczym zasilaniem. W projekcie jest wykorzystywany do wzmacniania sygnału analogowego z mikrokontrolera z zakresu 0 − 3.3 V na zakres 0 − 10 V aby ESP32 mógł sterować pompą. [15].

### 4.2.7 Elementy pasywne

- Rezystory: O wartościach od 200 Ω do 47 kΩ, stosowane do ograniczania prądu, podciągania linii sygnałowych oraz ustalania parametrów układów.
- Kondensatory: O pojemnościach 0.1 µF, 22 µF i 47 µF, używane do filtrowania napięć i stabilizacji pracy układów.
- Indukcyjność 4.7 µH: Wykorzystywana w obwodzie przetwornicy MP2315 do zapewnienia odpowiedniej filtracji i stabilizacji napięcia wyjściowego.

### 4.2.8 Diody LED

Diody LED pełnią funkcje sygnalizacyjne, informując o stanie pracy urządzenia, takich jak zasilanie, aktywność modułów czy wystąpienie błędów.

Paweł Krutak

## 4.3 Kosztorys

Tabela 4.1: Kosztorys komponentów

Nazwa produktu | Koszt [PLN] | Ilość | Link do produktu
ESP32-DEVKITV1 | 49,90 | 1 | [9]
RTC DS1307 z EEPROM 24C32 | 5,95 | 1 | [20]
Wyświetlacz OLED 1,3"(niebieski) | 29,90 | 1 | [21]
Encoder obrotowy KY-040 | 7,90 | 1 | [7]
Przetwornica DC-DC MP2315 | 6.58 | 1 | [26]
Wzmacniacz operacyjny LM358P | 7,20 | 5 | [10]
Rezystory i Kondensatory (zestaw) | 15 | zestaw
Diody LED | 1,90 | 10 | [8]
Przewody | 17,50 | 120 | [11]

Całkowity koszt komponentów użytych w projekcie, takich jak ESP32-DEVKITV1 (49,90 PLN), RTC DS1307 z EEPROM 24C32 (5,95 PLN), wyświetlacz OLED 1,3"(29,90 PLN), trzy encodery obrotowe KY-040 (łącznie 23,70 PLN), przetwornica DC-DC MP2315 (6,58 PLN), zestaw pięciu wzmacniaczy LM358P (7,20 PLN), rezystory i kondensatory (15,00 PLN), diody LED (1,90 PLN za 10 sztuk) oraz przewody połączeniowe (17,50 PLN), wynosi 157,73 PLN, co zostało szczegółowo przedstawione w tabeli 4.1.

4.4 Wybór Komponentów.

Wybór komponentów został oparty na analizie wymagań projektu.

4.4.1 Zmiana napięcia wejściowego.

Sygnały zewnętrzne, takie jak sygnał z zaworu EV oraz z system zarządzania budynkiem "BMS", dostarczane są w zakresie 0 − 10 V, co jest typowe dla przemysłowych systemów sterowania. Jednakże mikrokontroler ESP32 pracuje na napięciach wejściowe w zakresie 0 − 3.3 V. Dlatego jesteśmy zmuszeni przeskalować tą wartość z zakresu 0 − 10 V na zakres 0 − 3.3 V. Aby rozwiązać ten problem, zastosowano dzielnik napięcia. Schemat dzielnika opisuje rysunek 4.6, który przekształca napięcie wejściowe 0 − 10 V na zakres obsługiwany przez ESP32.

Rozdział 4. Hardware

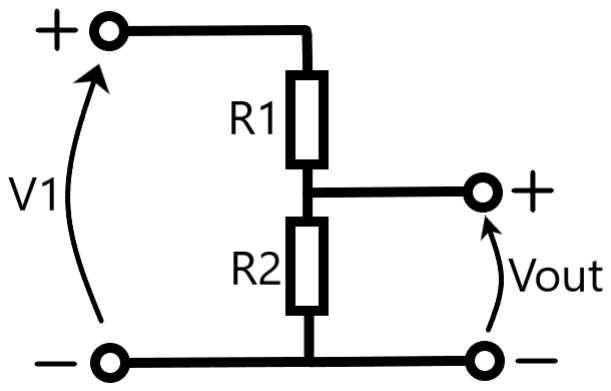
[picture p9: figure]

Rysunek 4.6: Dzielnik napięcia.

Wzór na przetwarzanie napięcia w sposób liniowy opisuje wzór - dzielnik napięcia (1) [6]:

Vout = V1 ·

R2
R1 + R2

(1),

gdzie:

- Vout — napięcie wyjściowe,
- V1 — napięcie wejściowe,
- R1 — rezystancja pierwszego rezystora,
- R2 — rezystancja drugiego rezystora.

Ze względu na brak rezystorów o dokładnych wartościach nominalnych, zastosowano układ zastępczy oparty na sumie szeregowo połączonych rezystancji - opisuje wzór (2) [6]:

Rtotal = R1 + R2 + R3 + . . . + Rn (2),

gdzie:

- Rtotal - całkowita rezystancja układu,
- R1, R2, R3, . . . , Rn - rezystancje poszczególnych rezystorów połączonych szeregowo.

Przy napięciu wejściowym V1 = 10V oraz rezystorach R1 = 13800 Ω i R2 = 6800 Ω, napięcie wyjściowe według wzoru wyniosło:

Vout =

V1 · R2
R1 + R2

=

10 · 6800
13800 + 6800

= 3.30V (1).

Paweł Krutak

Rezystory posiadają pewną swoją tolerancję, która w przypadku użytych elementów wynosiła 5%, co spowodowało minimalne odchylenia od zamierzonych wartości rezystancji w dzielniku napięcia.

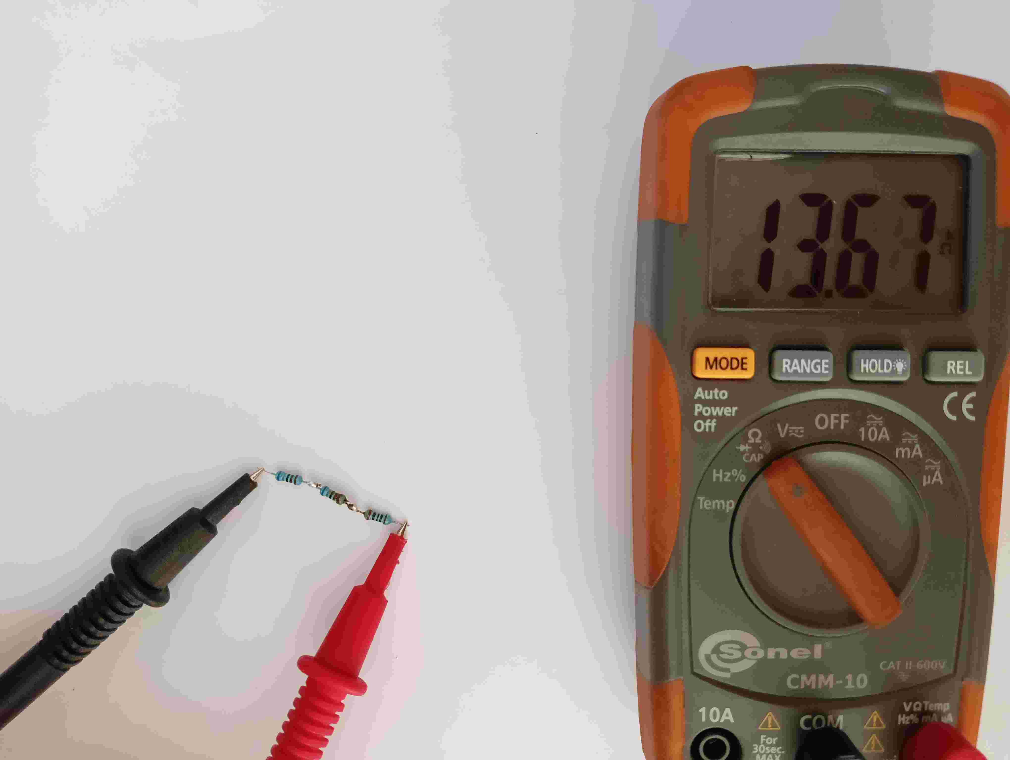
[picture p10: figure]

(a) Wartość rezystancji rezystora R1 dzielnika napięcia dla sygnału EV.
(b) Wartość rezystancji rezystora R2 dzielnika napięcia dla sygnału EV.
(c) Wartość rezystancji rezystora R1 dzielnika napięcia dla sygnału wejściowego z pompy.

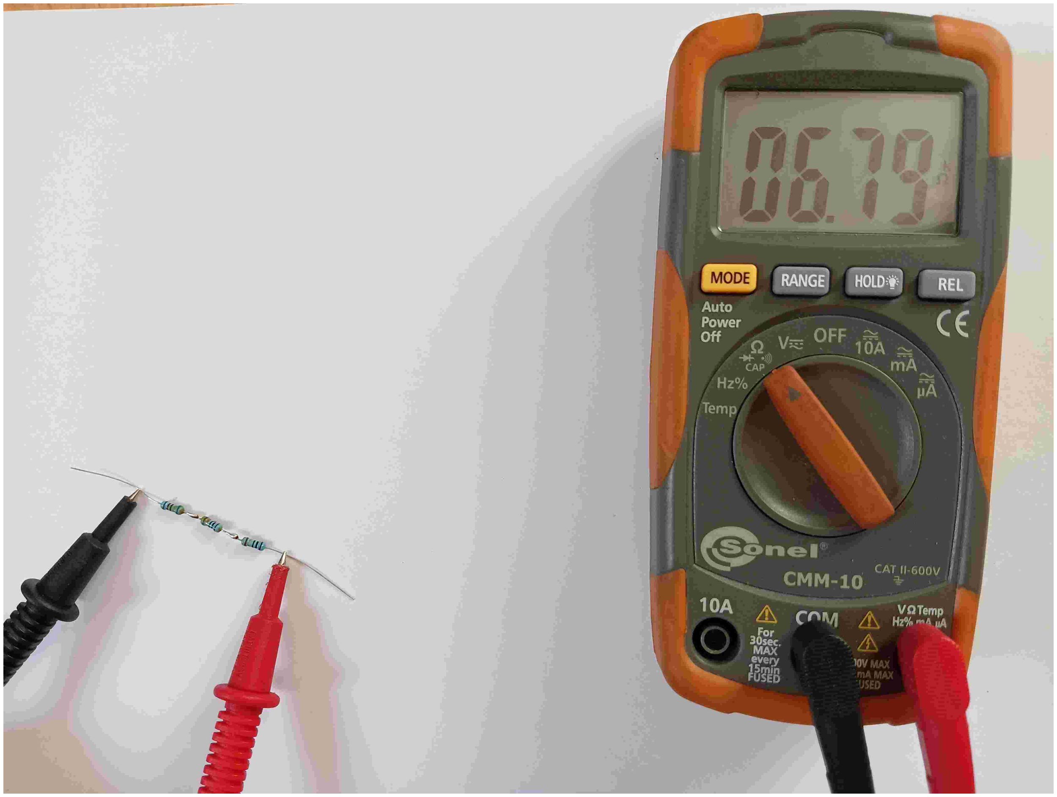
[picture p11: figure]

(d) Wartość rezystancji rezystora R2 dzielnika napięcia dla sygnału wejściowego z pompy.

Rysunek 4.7: Zmierzone wartości rezystancji rezystorów omomierzem.

Te rezystory przedstawione na rysunku 4.7 wykorzystano do analizy liniowości układu wejściowego, którą opisano w rozdziale szóstym, dlatego istotne było udokumentowanie rezystancji tych oporników. Dla zmierzonych wartości rezystancji - uzyskano następujące wyniki:

- Dla sygnału wejściowego z położenia kuli zaworu - EV:

Vout =

V1 · R2
R1 + R2

=

10 · 6740
13670 + 6740

= 3.30V (1).

- Dla sygnału wejściowego z pompy - BMS:

Vout =

V1 · R2
R1 + R2

=

10 · 6790
13760 + 6790

= 3.30V (1).

Rozdział 4. Hardware

4.4.2 Zmiana napięcia wyjściowego.

Aby przekształcić sygnał wyjściowy mikrokontrolera z zakresu 0 − 3.3 V na 0 − 10 V, zastosowano wzmacniacz operacyjny LM358P w konfiguracji nieodwracającej [19]. Tego rodzaju konfiguracja wzmacniacza pozwala na wzmocnienie sygnału wejściowego Uin bez odwracania jego fazy, co zapewnia liniowe zwiększenie napięcia w tym zakresie napięciowym.

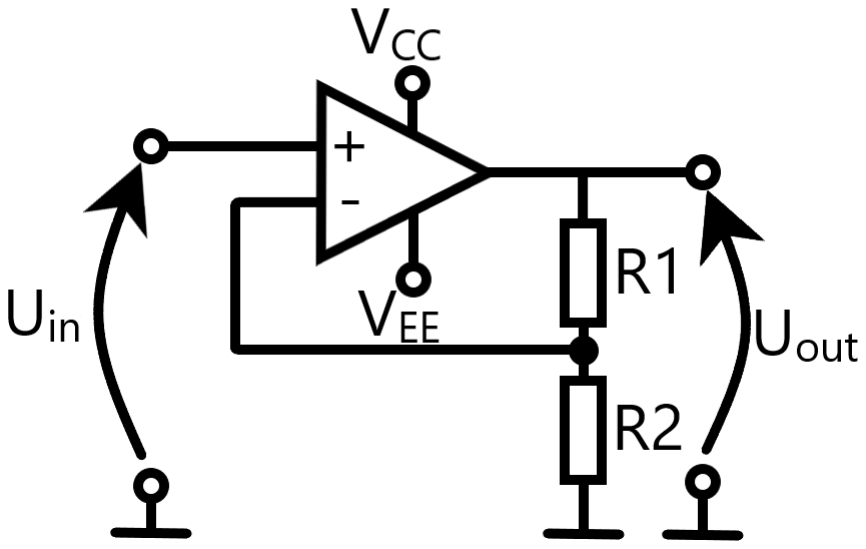
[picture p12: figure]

Rysunek 4.8: Wzmacniacz operacyjny w konfiguracji wzmacniacza nieodwracającego.

Wzmacniacz nieodwracający fazy jest opisany na schemacie - rysunek 4.8. Zależność między napięciem wejściowym Uin, napięciem wyjściowym Uout oraz wzmocnieniem k opisana jest równaniem (3) [19]:

Uout = k · Uin =

1 +

R1
R2
- Uin (3).

Współczynnik wzmocnienia k można obliczyć na podstawie wartości rezystorów R1 oraz R2 według poniższego wzoru (4) [19]:

k = 1 +

R1
R2

(4),

gdzie:

- Uin — napięcie wejściowe,
- Uout — napięcie wyjściowe,
- R1 — rezystor w gałęzi sprzężenia zwrotnego,
- R2 — rezystor w gałęzi wejściowej,
- k — współczynnik wzmocnienia wzmacniacza.

Paweł Krutak

Aby uzyskać odpowiednie wzmocnienie k =

10
3.3 = 3.03 (4), wybrano wartości rezystorów R1 = 20.3 kΩ oraz R2 = 10 kΩ. Takie wartości zapewniają prawidłowe przeskalowanie sygnału, umożliwiając przetworzenie napięcia wejściowego w zakresie 0 − 3.3 V na napięcie wyjściowe w zakresie 0 − 10 V, co jest wymagane do sterowania pompą.
W celu zapewnienia poprawności wartości użytych rezystorów, zostały one zmierzone za pomocą multimetru, rysunek 4.9. Pomiar rezystancji potwierdził zgodność z wartościami teoretycznymi oporności rezystorów, co jest istotne dla prawidłowego działania układu, poniważ zakupione rezystory mają tolerancję równą 5%. Te rezystory zostały wykorzystane do badania liniowości układu wyjściowego, które jest opisane w rozdziale szóstym, dlatego istotne było udokumentowanie rezystancji tych oporników.
(a) Wartość rezystancji rezystora R1 | (b) Wartość rezystancji rezystora R2

Rysunek 4.9: Zmierzone wartości rezystancji rezystorów omomierzem.

Powyższa konfiguracja wzmacniacza operacyjnego, rysunek 4.8, zapewnia stabilne i liniowe wzmocnienie sygnału wejściowego bez odwrócenia jego fazy, co jest kluczowe do precyzyjnej kontroli napięcia wyjściowego zadajnika.

### 4.4.3 Wybór Przetwornicy Impulsowej do Konwersji Napięcia

W projekcie konwersji napięcia z 12V na 5V wybrano przetwornicę impulsową typu buck (step-down) MP2315. Wybór ten był podyktowany wysoką efektywnością energetyczną, możliwością dostarczenia stabilnego prądu oraz kompaktową konstrukcją, co sprawia, że idealnie nadaje się do implementacji na płytce PCB (lutowanie w technologii SMD) [26].
Alternatywne rozwiązania, takie jak stabilizatory liniowe (np. LM7805), zostały odrzucone z powodu znacznych strat mocy i wynikającego z tego wydzielania ciepła. Przy konwersji z 12V do 5V stabilizator liniowy rozpraszałby dużą ilość energii cieplnej, co wymagałoby stosowania radiatorów i zwiększyłoby rozmiar układu. Stabilizator liniowy nie jest również zalecany przy prądach bliskich 1A, gdyż w takich warunkach obniża sprawność i znacząco zwiększa zapotrzebowanie na chłodzenie.

Rozdział 4. Hardware

Rozważano także przypadki z innymi przetwornicami impulsowymi o niższych specyfikacjach, np. LMR16006, które zapewniają wyższą sprawność niż stabilizatory liniowe, ale obsługują jedynie prądy do 0,6A. Natomiast przetwornica impulsowa MP2315 może dostarczyć do 3A prądu wyjściowego [26], dlatego zapewnia większy margines bezpieczeństwa i stabilność pracy przy wymaganym obciążeniu 1A, co minimalizuje ryzyko przeciążenia i przedłuża żywotność komponentów.

Obliczenia Rezystorów Dzielnika Napięcia

Do ustawienia napięcia wyjściowego przetwornicy na poziomie 5V zastosowano dzielnik napięcia aby dobrać rezystory do pętli sprzężenia zwrotnego przetwornicy, opierając się na wzorze (5):

VOUT = VREF ×

1 +

R1
R2
(5),

gdzie:

- VOUT to napięcie wyjściowe ustawione na 5 V,
- VREF to wewnętrzne napięcie referencyjne wynoszące 0,8 V,
- R1 i R2 to rezystory dzielnika napięcia.

Z przekształcenia wzoru (5) uzyskano stosunek:

R1
R2

=

5V
0,8V

− 1 = 4,98 (6).

Na podstawie wzoru (6) dobrano standardowe wartości rezystorów:

- R1 = 47 kΩ,
- R2 = 9 kΩ.

Dobór Dodatkowych Komponentów

Dla stabilności układu dodano kondensator wejściowy 22 µF (ceramiczny X7R) i kondensator wyjściowy 44 µF. Zastosowano również cewkę o indukcyjności 5,5 µH i prądzie znamionowym 3A, co zachowuje równowagę między wymogami prądowymi, a rozmiarami komponentów.
Dzięki technologii synchronizacji i wysokiej częstotliwości przełączania (500 kHz) przetwornica MP2315 zapewnia wysoką sprawność, minimalizując wydzielanie ciepła i zapewniając stabilne zasilanie przy prądzie wyjściowym do 1A.
Wybrano rezystory o tolerancji 5% ze względu na ich dostępność i wystarczającą dokładność dla założeń projektowych.

Paweł Krutak

4.4.4 | Wybór | Encoderów | Zamiast | Potencjometrów | do
Zadawania Wartości.

W projekcie do zadawania wartości zamiast klasycznych potencjometrów zdecydowano się na zastosowanie encoderów obrotowych. Główną zaletą encoderów jest ich wysoka precyzja oraz możliwość uzyskania większej liczby punktów nastawczych, co umożliwia dokładniejsze sterowanie parametrami układu. Encodery obrotowe, w odróżnieniu od potencjometrów, nie podlegają efektom zużycia styków i są bardziej odporne na zmienne warunki środowiskowe, co zwiększa ich niezawodność oraz żywotność w aplikacjach wymagających wielokrotnego ustawiania wartości.
Dodatkowo, encodery umożliwiają bezpośrednią integrację z cyfrowym interfejsem mikrokontrolera (wyświetlacz OLED), co upraszcza kontrolę i pozwala na cyfrową interpretację zmian pozycji. Encodery oferują również funkcję przycisku, co umożliwia wprowadzenie dodatkowych komend dla użytkownika i jest nieosiągalne w przypadku standardowych potencjometrów.

### 4.4.5 Wskaźniki LED na Wejściach i Wyjściu Układu

W projekcie zastosowano diody LED, które pełnią funkcję wskaźników obecności napięcia na wejściach i wyjściu układu. Diody te świecą, gdy na odpowiednich pinach podawane jest napięcie, co zapewnia wizualne potwierdzenie działania układu. Dzięki zastosowaniu LED, użytkownik może łatwo monitorować stan zasilania bez konieczności korzystania z dodatkowych przyrządów pomiarowych.

### 4.4.6 Wyświetlacz do Wizualizacji Parametrów Układu i Czasu

W projekcie zastosowano wyświetlacz OLED o rozdzielczości 128x64 pikseli, który pozwala na monitorowanie kluczowych parametrów pracy układu, takich jak zadana wartość napięcia, aktualne napięcie wyjściowe oraz stan systemu. Dodatkowo, wyświetlacz będzie prezentował bieżący czas, pozyskiwany z modułu RTC (Real Time Clock), co umożliwia śledzenie parametrów w kontekście aktualnego czasu. Dzięki wyświetlaczowi OLED informacje są czytelne i łatwo dostępne dla użytkownika.

4.5 | Projektowanie | oraz | wykonanie | płytki

drukowanej.

W ramach pracy inżynierskiej wykonano projekt płytki drukowanej (PCB) z wykorzystaniem oprogramowania EAGLE przedstawionej na rysunku 4.10. Proces projektowania obejmował rozmieszczenie elementów na płytce oraz prowadzenie ścieżek

Rozdział 4. Hardware

sygnałowych i zasilających zgodnie z założeniami projektowymi. W projekcie zastosowano różne szerokości ścieżek w zależności od poziomów napięć i rodzajów sygnałów:

- Ścieżki zasilające 12 V (50 mils) zaprojektowano dla minimalizacji spadków napięcia

przy wyższych prądach.

- Dla ścieżek zasilających 5 V przyjęto szerokość 40 mils, co zapewnia optymalne parametry pracy układu.
- Ścieżki dla napięcia 3,3 V posiadają szerokość 30 mils, co jest wystarczające dla

układów niskonapięciowych.

- Linie masy (GND) o szerokości 50 mils minimalizują zakłócenia i zapewniają stabilność układu.
- Sygnały analogowe prowadzono ścieżkami o szerokości 20 mils, co umożliwia ograniczenie wpływu zakłóceń elektromagnetycznych.
- Sygnały cyfrowe zaprojektowano z szerokością ścieżek 15 mils, co jest odpowiednie dla poprawnego przesyłu danych.

Paweł Krutak

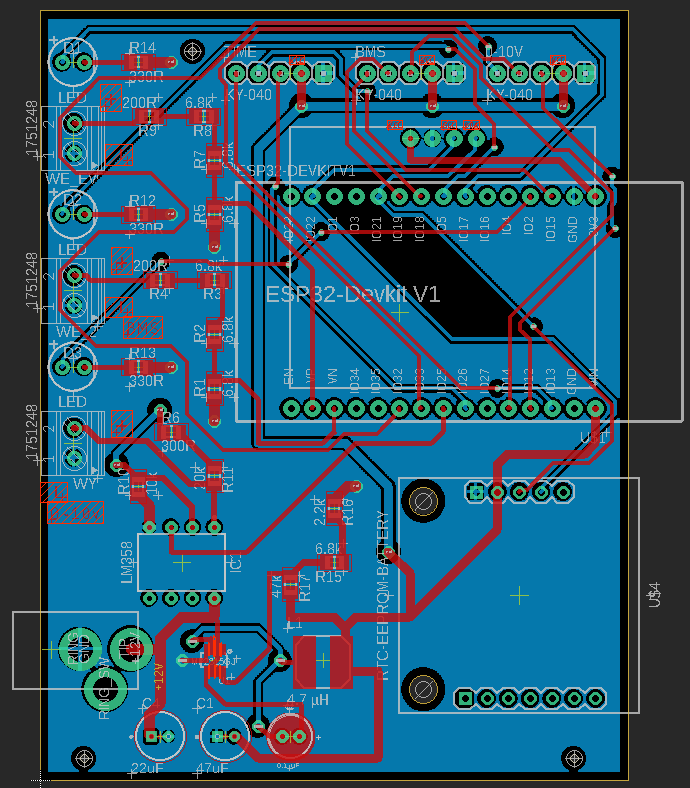
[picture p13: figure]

(a) Zaprojektowana płytka PCB w programie

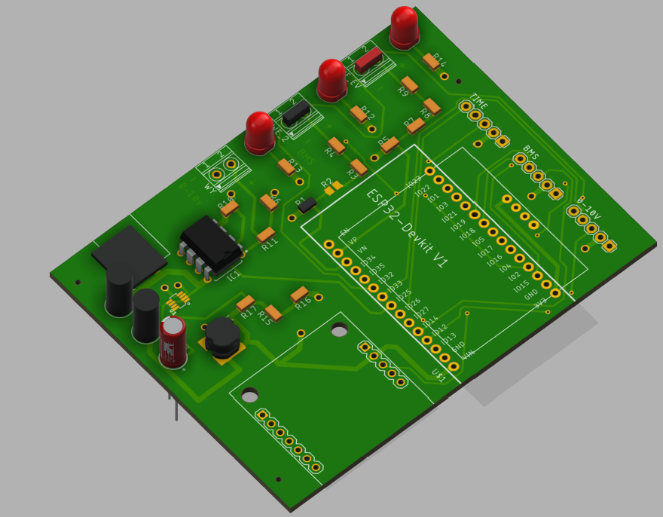
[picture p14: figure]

EAGLE. | (b) Model płytki PCB w programie FUSION.

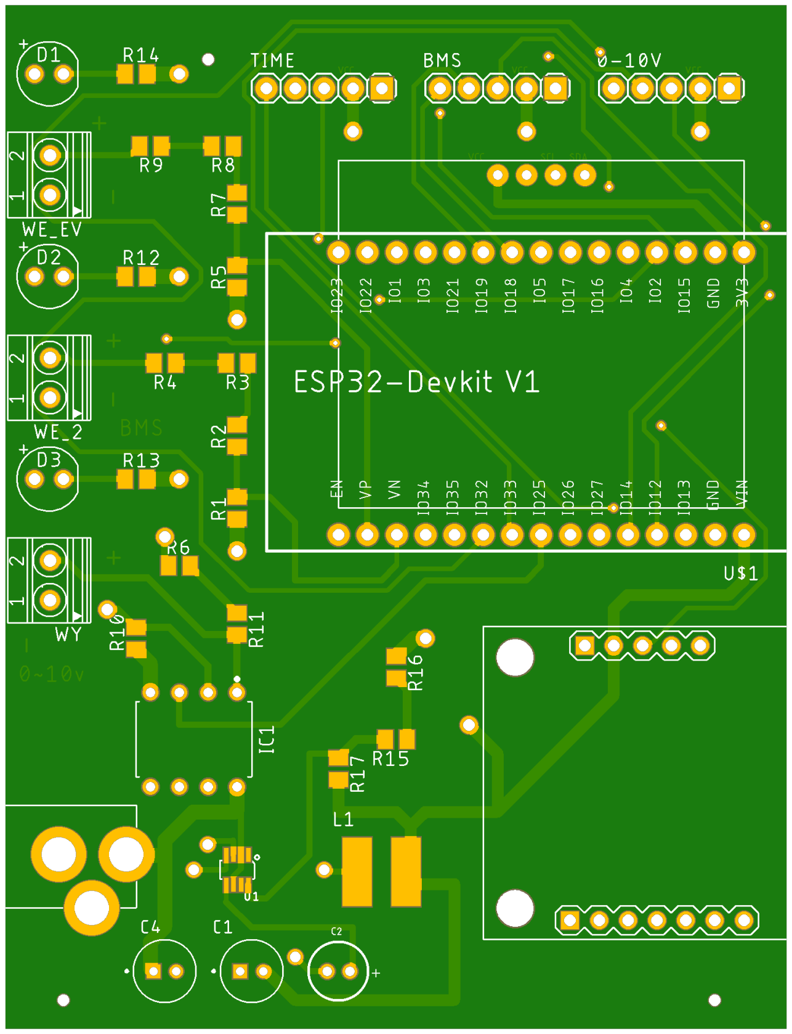
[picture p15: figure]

(c) Wygenerowany obraz górnej warstwy w programie EAGLE.

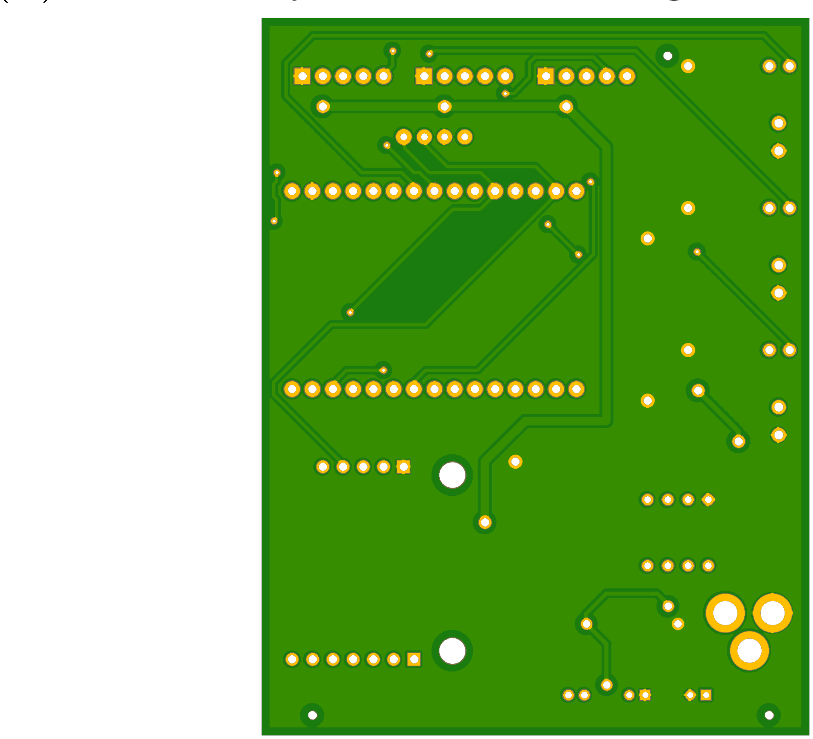
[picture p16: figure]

(d) Wygenerowany obraz dolnej warstwy w programie EAGLE.

Rysunek 4.10: Model zaprojektowanej płytki PCB.

Na dolnej warstwie zaprojektowano wylaną miedź pełniącą funkcję wspólnej masy (GND). Takie rozwiązanie zapewnia lepsze właściwości elektryczne, redukuje impedancję masy oraz dodatkowo minimalizuje zakłócenia elektromagnetyczne w układzie.
W trakcie prac projektowych szczególnie przydatna okazała się dokumentacja oprogramowania EAGLE [4], która dostarczyła istotnych informacji na temat projektowania układów PCB, takich jak zasady tworzenia wylewek masy, konfiguracja szerokości ścieżek oraz eksport plików Gerber do produkcji. Dzięki tym wskazówkom możliwe było optymalne zaprojektowanie płytki PCB.
Ostateczny projekt płytki został wyeksportowany w formacie Gerber i wydrukowany przez firmę PCBWay, co zapewniło wysoką jakość wykonania oraz zgodność z założeniami projektowymi. Po dostarczeniu zamówionych komponentów oraz

Rozdział 4. Hardware

wydrukowanej płytki PCB przystąpiono do procesu lutowania elementów w technologii SMD i THT, co umożliwiło zmontowanie i uruchomienie układu zgodnie z założeniami projektowymi. Do lutowania wykorzystano lutownicę HotAir oraz lutownicę oporową. Końcowy wygląd płytki drukowanej znajduje się na rysunku 4.11.

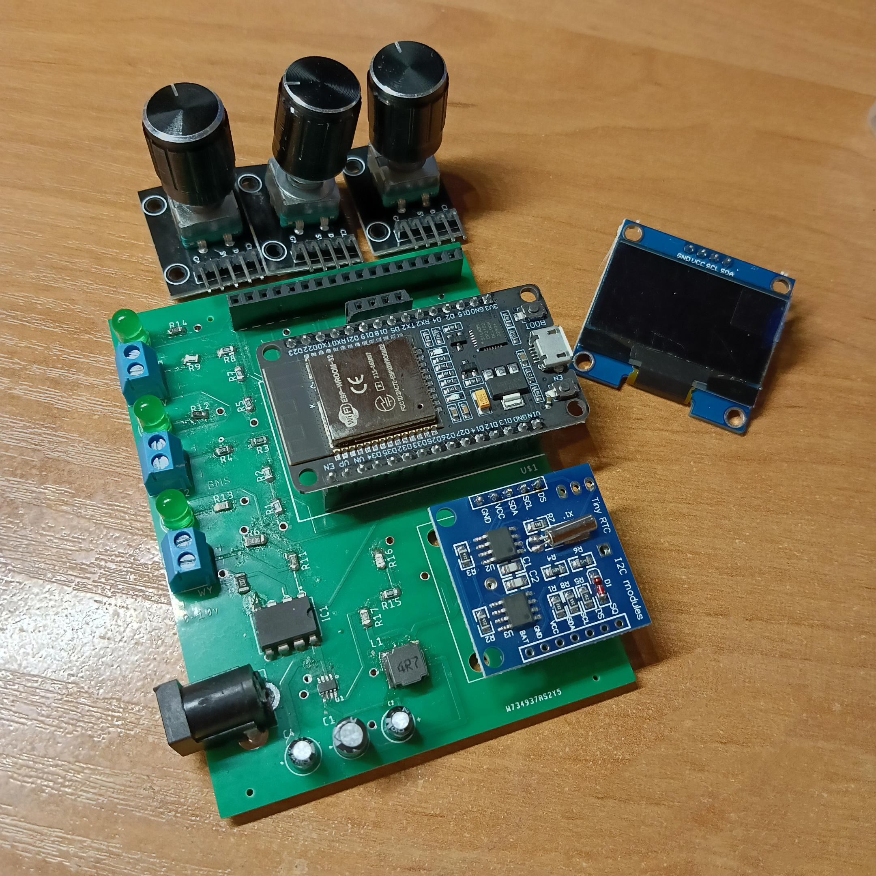
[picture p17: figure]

Rysunek 4.11: Płytka drukowana z przylutowanymi komponentami.

Paweł Krutak

4.6 Projektowanie i wydruk obudowy.

Proces projektowania i wytwarzania obudowy dla zadajnika obejmował kilka kluczowych etapów, poczynając od stworzenia modelu 3D w programie Autodesk Inventor [3], a kończąc na wydruku elementów przy użyciu drukarki 3D.
Autodesk Inventor jest jednym z najbardziej zaawansowanych narzędzi do
projektowania | CAD | (Computer-Aided | Design), | pozwalającym | na | tworzenie
precyzyjnych modeli 3D oraz symulacje mechaniczne [3]. W ramach projektu zaprojektowano obudowę składającą się z dwóch głównych części - górnej i dolnej.
Obudowa | została | zaprojektowana | z | uwzględnieniem | wymiarów | komponentów
elektronicznych | oraz | otworów | dla | zasilania | wejść | oraz | wyjścia | zadajnika.
Zaprojektowana obudowa znajduje się na rysunku 5.27.

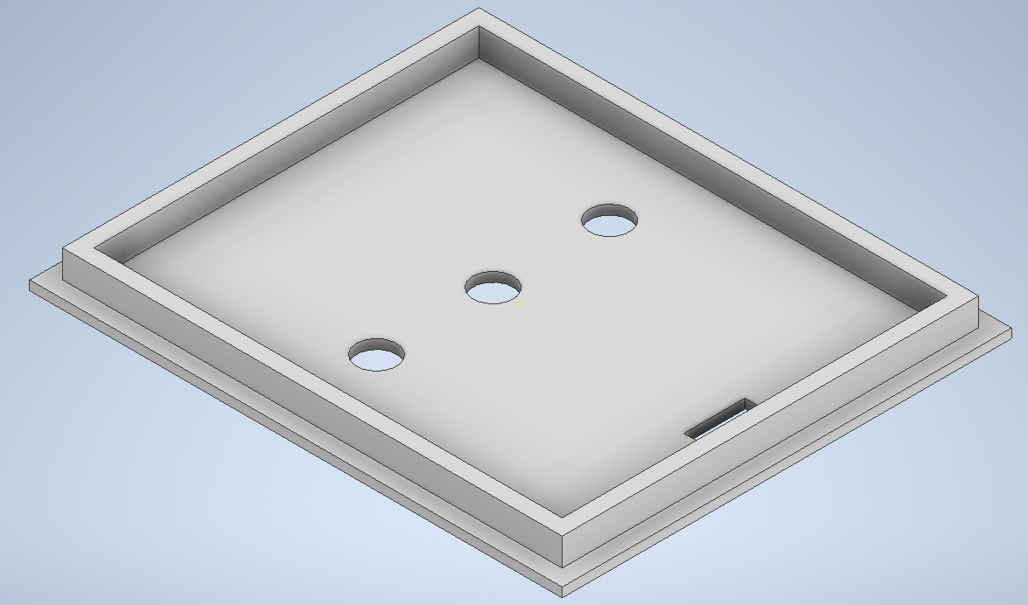
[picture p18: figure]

(a) | Zaprojektowana | obudowa | górna
w programie Inventor - widok z góry.

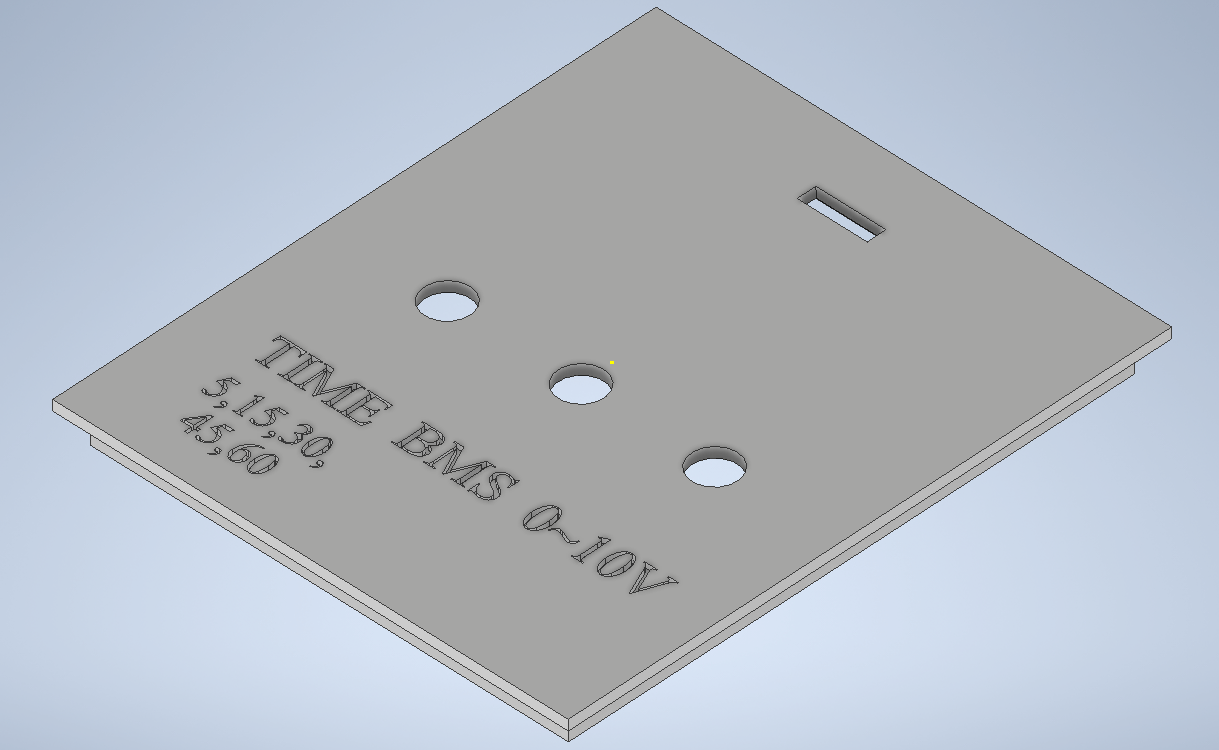
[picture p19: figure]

(b) | Zaprojektowana | obudowa | górna
w programie Inventor - widok z dołu.

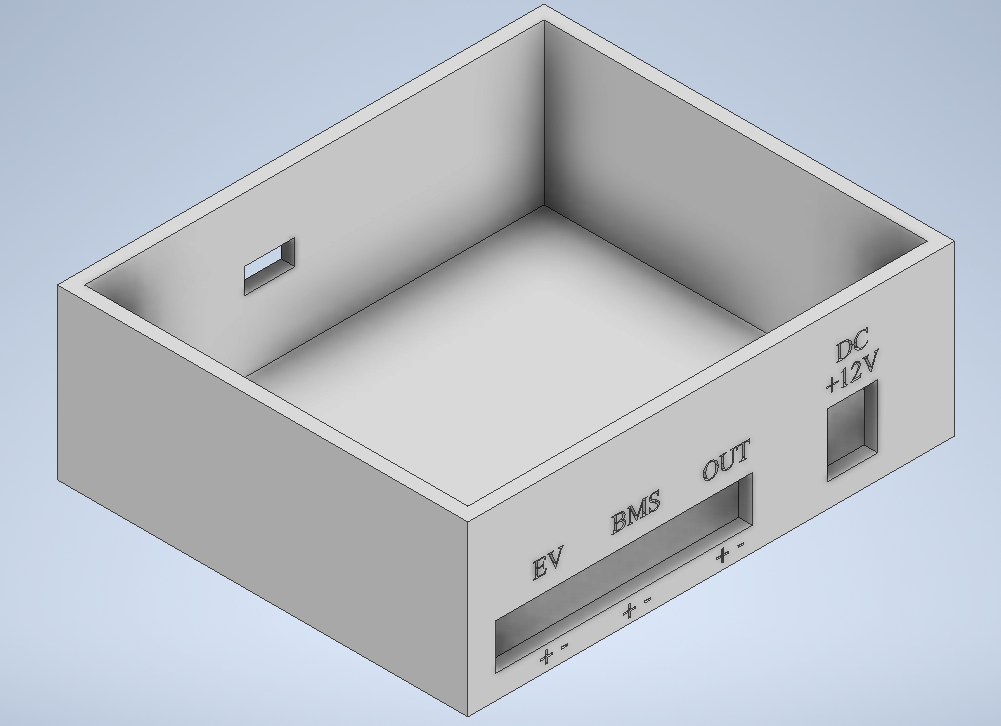
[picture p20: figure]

(c) | Zaprojektowana | obudowa | dolna
w programie Inventor.

Rysunek 4.12: Model zaprojektowanej obudowy w programie Inventor.

Gotowy model 3D został wyeksportowany w formacie STL, co pozwoliło na jego obróbkę w slicerze kompatybilnym z drukarką 3D Bambu Lab A1 [17]. Drukarka ta jest wyposażona w zaawansowane funkcje, takie jak automatyczna kalibracja stołu oraz obsługa wielomateriałowych wydruków, co gwarantuje wysoką precyzję i jakość

Rozdział 4. Hardware

wykonanych elementów.
Do wydruku obudowy wykorzystano filament PET-G [2], który charakteryzuje się:
- wysoką odpornością na temperaturę i promieniowanie UV,
- dobrą wytrzymałością mechaniczną,
- niską absorpcją wilgoci,
- łatwością przetwarzania na drukarkach 3D.

Proces drukowania został podzielony na dwa etapy: wydruk dolnej i górnej części obudowy. Każda część obudowy została zaprojektowana tak, aby precyzyjnie dopasować górną część do dolnej bez potrzeby stosowania dodatkowych elementów mocujących.

Paweł Krutak

4.7 | Końcowy | wygląd | elektronicznego
| optymalizatora.

Prezentacja końcowego wyglądu zadajnika ukazuje pełną integrację komponentów elektronicznych wraz z obudową, co stanowi kluczowy etap realizacji założeń projektowych. Na rysunku 4.13 zaprezentowano ostateczny wygląd zadajnika po procesach lutowania oraz wydrukowania obudowy.

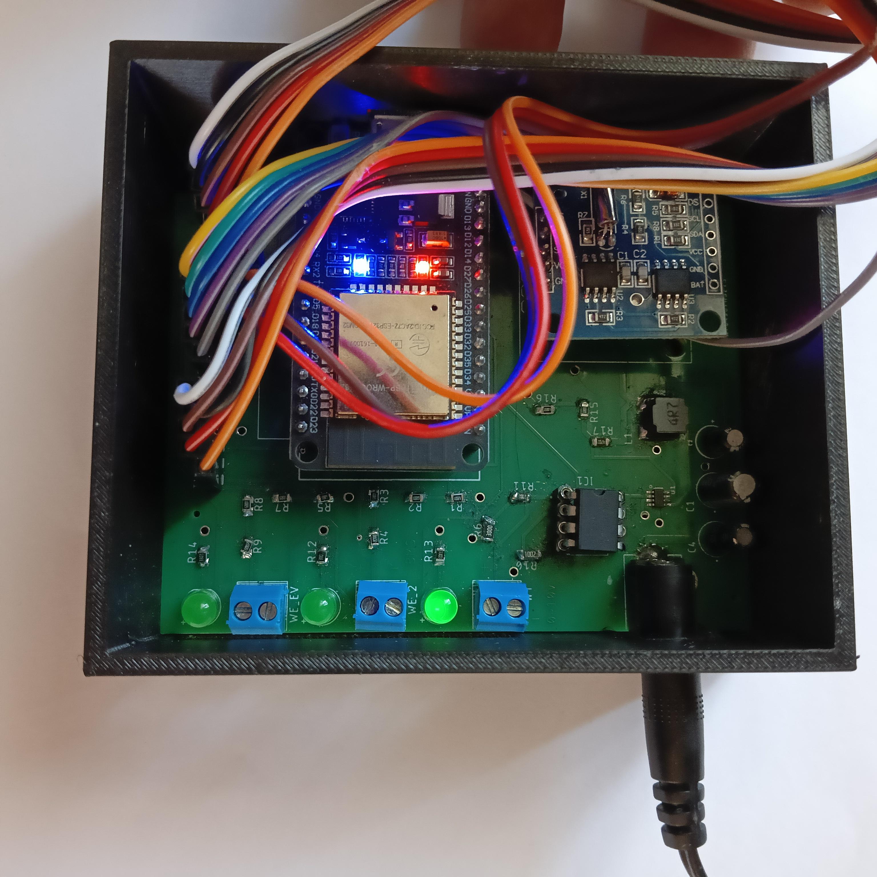
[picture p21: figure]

(a) Wygląd zadajnika w środku obudowy.

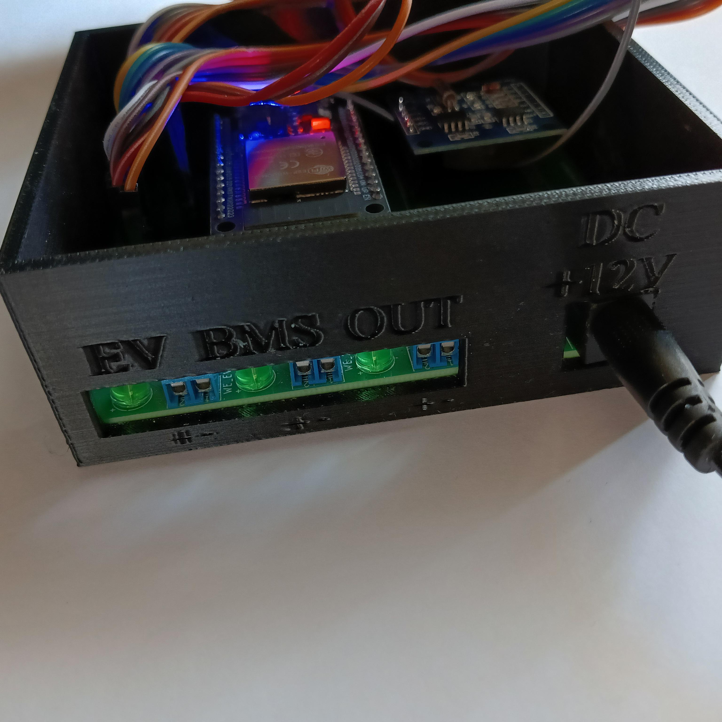
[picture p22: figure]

(b) Wygląd zadajnika - widok na wejścia i wyjście układu.

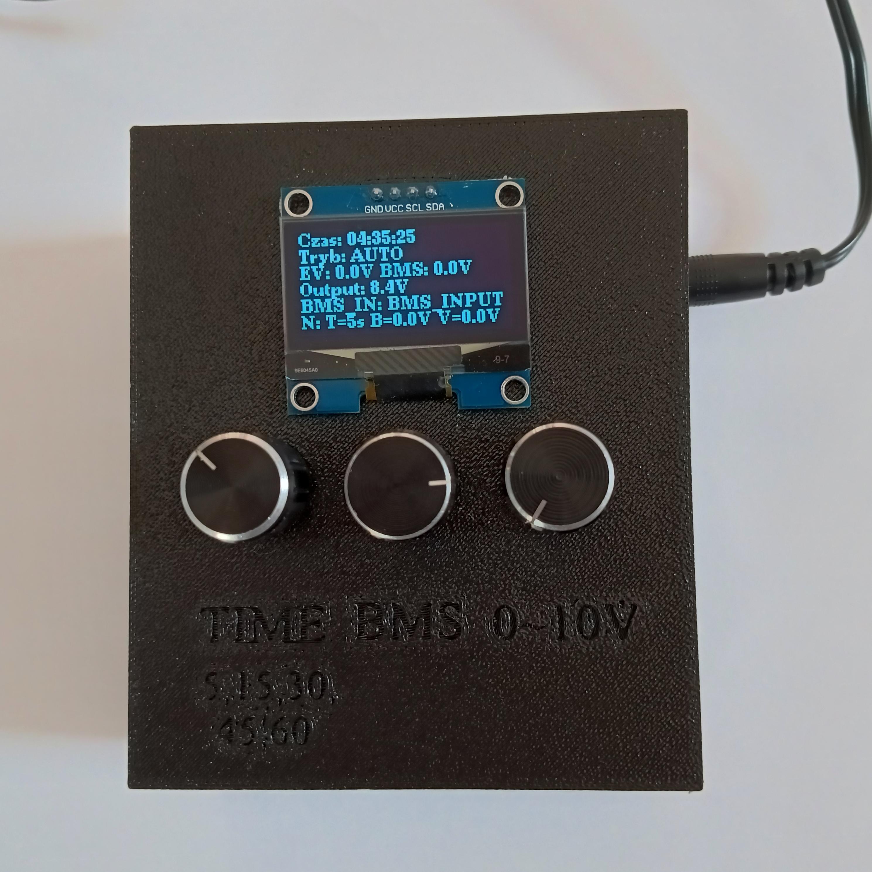
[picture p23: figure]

(c) Wygląd zadajnika - widok z góry.

Rysunek 4.13: Końcowy wygląd zaprojektowanego zadajnika.

# Rozdział 5

# Software

W | niniejszym | rozdziale | przedstawiono | implementację | kodu | zadajnika
zaprojektowanego w celu realizacji funkcji związanych z automatycznym sterowaniem pompą. Zadajnik został opracowany na mikrokontrolerze ESP32, co umożliwia integrację różnych peryferiów oraz realizację złożonych algorytmów przetwarzania danych. Opracowany system charakteryzuje się modułowością oraz elastycznością, co pozwala na jego adaptację w różnych warunkach pracy.

Główne funkcje zadajnika obejmują regulację pracy pompy w trybie automatycznym i manualnym, z uwzględnieniem odczytów z systemu zarządzania budynkiem (BMS) oraz informacji o położeniu kuli zaworu. System umożliwia również obsługę wejść analogowych i cyfrowych, w tym precyzyjny odczyt napięć z wejść oraz obsługę encoderów używanych do ustawiania parametrów pracy. Komunikacja z urządzeniami peryferyjnymi odbywa się za pomocą magistrali I²C, co obejmuje moduł czasu rzeczywistego (RTC) oraz wyświetlacz OLED, umożliwiający wizualizację danych procesowych. Ponadto zadajnik wykorzystuje zaawansowane algorytmy przetwarzania sygnałów pomiarowych, takie jak interpolacja, korekta offsetu oraz wygładzanie eksponencjalne, co zapewnia stabilność i precyzję działania.

Ostateczne sterowanie wyjściowe realizowane jest poprzez generowanie sygnałów PWM oraz zarządzanie sygnałami analogowymi i cyfrowymi, które sterują urządzeniami wykonawczymi, takimi jak pompa czy wyświetlacz. W dalszej części rozdziału szczegółowo omówiono wykorzystane biblioteki, przypisanie funkcji do poszczególnych pinów mikrokontrolera, algorytmy przetwarzania danych oraz logikę regulacji w obu trybach pracy. Przedstawienie tych elementów ma na celu przybliżenie zarówno aspektów technicznych, jak i uzasadnienia zastosowanych rozwiązań, co pozwala na lepsze zrozumienie funkcjonowania zadajnika w kontekście realizowanego projektu.

Paweł Krutak

5.1 Kod zadajnika.

5.1.1 Opis wykorzystanych bibliotek.

1 | # include < Arduino .h >
2 | # include < Wire .h >
3 | # include < U8g2lib .h >
4 | # include < RTClib .h >
5 | # include < esp_adc_cal .h >

Rysunek 5.1: Wykorzystane biblioteki.

Na rysunku 5.1 znajduje się fragment kodu do zaimportowania pięciu bibliotek, które są niezbędne do realizacji funkcjonalności programu:

- Biblioteka Arduino.h [27]
Biblioteka ta jest integralną częścią środowiska programistycznego Arduino i zapewnia dostęp do podstawowych funkcji oraz definicji umożliwiających komunikację z mikrokontrolerem. Przykładowe funkcje, które udostępnia, to:

– digitalRead() i digitalWrite() do odczytu i zapisu stanów na pinach cyfrowych,

– analogRead() i analogWrite() do obsługi wejść i wyjść analogowych,

– millis() do pomiaru czasu od uruchomienia urządzenia.

Biblioteka Arduino.h jest fundamentem, na którym budowane są wszystkie bardziej zaawansowane opcje programu.

- Biblioteka Wire.h [28]
Wire.h umożliwia komunikację przez magistralę I²C (Inter-Integrated Circuit), co jest szczególnie istotne w przypadku urządzeń peryferyjnych takich jak moduły RTC czy wyświetlacze OLED. Umożliwia ona inicjalizację magistrali oraz przesyłFanie danych pomiędzy urządzeniami w prosty sposób. W projekcie magistrala I²C jest wykorzystywana do komunikacji z:

– zegarem czasu rzeczywistego (RTC),

– wyświetlaczem OLED.

- Biblioteka U8g2lib.h [16]
Biblioteka ta służy do obsługi wyświetlaczy graficznych OLED. Umożliwia ona wyświetlanie tekstu, kształtów graficznych oraz wybór czcionek o różnych rozmiarach. W projekcie wyświetlacz OLED pełni kluczową rolę w prezentacji informacji o stanie systemu w czasie rzeczywistym, takich jak bieżący czas,

Rozdział 5. Software

aktualne wartości nastaw, odczytanych wartości wejściowych, wiadomość o wartości wyjściowej oraz aktualny tryb pracy.

- Biblioteka RTClib.h [1]
RTClib.h wspiera ona komunikację z zegarami czasu rzeczywistego (RTC). Moduły RTC umożliwiają synchronizację systemu z rzeczywistym czasem kalendarzowym, co jest kluczowe w aplikacjach wymagających precyzyjnego ustalania harmonogramowania działań, np. regulacji napięcia w określonych przedziałach czasowych. Biblioteka ta oferuje funkcje takie jak:

– inicjalizacja modułu RTC,

– odczyt bieżącej daty i czasu,

– automatyczna aktualizacja czasu podczas resetu mikrokontrolera.

- Biblioteka esp_adc_cal.h [23]
Biblioteka kalibracyjna dla wbudowanego przetwornika analogowo-cyfrowego (ADC) w mikrokontrolerze ESP32. ESP32 posiada funkcje pomiaru napięcia na pinach wejściowych ADC, jednak ze względu na specyfikę sprzętową pomiary mogą być obarczone błędami. Biblioteka esp_adc_cal.h pozwala na:

– interpolację wyników odczytu ADC,

– zastosowanie kalibracji napięć referencyjnych,

– poprawę dokładności pomiarów napięciowych.

W projekcie biblioteka ta jest wykorzystywana do precyzyjnego odczytu napięć z położenia F EV i BMS.

5.1.2 Uzasadnienie zastosowania bibliotek.

Zastosowanie powyższych bibliotek umożliwia realizację złożonych zadań w prosty i modularny sposób. Użycie gotowych rozwiązań pozwala na redukcję błędów programistycznych oraz skrócenie czasu implementacji. Każda z zaimportowanych bibliotek pełni unikalną rolę, która wspiera zarówno obsługę sprzętową, jak i implementację funkcjonalności logicznych.

### 5.1.3 Opis zdefiniowanych pinów

Rysunek 5.2 przedstawia fragment kodu do definicji pinów dla mikrokontrolera, które odpowiadają za różne funkcje systemu. Zostały one przypisane do określonych elementów sprzętowych zgodnie ze schematem projektu. Poniżej znajduje się szczegółowy opis:

Paweł Krutak

1 | # define CLK_BMS 18
2 | # define DT_BMS 19
3 | # define CLK_VOLT 32
4 | # define DT_VOLT 33
5 | # define CLK_TIME 13
6 | # define DT_TIME 15
7 | # define BUTTON_PIN 26
8 | # define ENCODER_BUTTON_PIN 14
9 | # define ANALOG_OUT 25
10 | # define VP_PIN 36
11 | # define VN_PIN 39
12 | # define DIGITAL_OUT 2
13 | # define DIGITAL_BMS 5
14 | # define DIGITAL_EV 17

Rysunek 5.2: Definicja pinów mikrokontrolera.

- CLK_BMS (pin 18)
Pin wejściowy zegarowy dla encodera od nastawy BMS.
- DT_BMS (pin 19)
Pin odpowiedzialny za | odczyt danych | (Data) z | encodera związanego
z funkcjonalnością BMS. Wraz z sygnałem zegarowym umożliwia określenie kierunku i liczby impulsów encodera.
- CLK_VOLT (pin 32)
Służy jako wejście zegarowe dla encodera, od nastawy wartości wyjściowej w trybie manualnym. Działa w połączeniu z pinem DT_VOLT.
- DT_VOLT (pin 33)
Odpowiada za odczyt danych z encodera sterującego napięciem.
- CLK_TIME (pin 13)
Pin wejściowy zegarowy dla encodera, który służy do ustawiania interwałów czasowych regulacji o wartościach 5s, 15s, 30s, 45s oraz 60s.
- DT_TIME (pin 15)
Pin do odczytu danych z encodera obsługującego ustawienia czasowe. W połączeniu z CLK_TIME umożliwia zmianę interwałów czasu regulacji.
- BUTTON_PIN (pin 26)
Pin odpowiadający za obsługę przycisku encodera. Umożliwia ręczne przełączanie trybów pracy systemu.
- ENCODER_BUTTON_PIN (pin 14)
Pin obsługujący przycisk wbudowany w encoder. Służy do zmiany źródła wartości

Rozdział 5. Software

wejściowych pomiędzy BMS_INPUT a BMS_ENCODER, co pozwala na przełączanie trybu pracy w zależności od dostępności sygnału z systemu BMS.

- ANALOG_OUT (pin 25)
Wyjście analogowe, które steruje sygnałem napięciowym w zakresie od 0 V do 3.3
V. Wykorzystywane do sterowania pompą.
- VP_PIN (pin 36)
Pin ADC (Analog-to-Digital Converter), który jest używany do odczytu napięcia z położenia kuli zaworu EV. Napięcie to informuje o bieżącym położeniu zaworu.
- VN_PIN (pin 39)
Pin ADC 3, odpowiedzialny za odczyt napięcia z BMS’u. Napięcie to informuje o docelowej wartości silnika pompy i jest informacją priorytetową.
- DIGITAL_OUT (pin 2)
Wyjście cyfrowe sterujące diodą sygnalizacyjną. Służy do wskazywania, czy napięcie wyjściowe (sterujące zaworem) jest aktywne (+0.1 V).
- DIGITAL_BMS (pin 5)
Pin cyfrowy sterujący diodą sygnalizującą aktywność systemu BMS. Dioda zapala się, gdy napięcie na pinie VN przekracza minimalny próg (0.1 V).
- DIGITAL_EV (pin 17)
Pin cyfrowy odpowiedzialny za sygnalizację aktywności systemu zaworu. Dioda podłączona do tego pinu świeci, gdy napięcie pinu VP przekracza minimalny próg (0.1 V).

### 5.1.4 Konfiguracja wyświetlacza OLED

1 U8G2_SH1106_128X64_NONAME_F_HW_I2C u 8 g 2 (U8G2_R0, /* reset =*/ U8X8_PIN_NONE) ;

Rysunek 5.3: Definicja wyświetlacza OLED.

Na rysunku 5.3 definiujemy obiekt u8g2, który jest instancją klasy

U8G2_SH1106_128X64_NONAME_F_HW_I2C z biblioteki U8g2lib. Obiekt ten służy do obsługi wyświetlacza OLED o rozdzielczości 128x64 pikseli, korzystającego ze zadajnika SH1106 i sprzętowego interfejsu I²C [16].

Paweł Krutak

Parametry obiektu

- U8G2_R0 — Parametr określający orientację wyświetlacza jako domyślną (bez rotacji).
- U8X8_PIN_NONE — Wskazuje, że pin resetu nie jest używany. Reset wyświetlacza realizowany jest sprzętowo lub w sposób wewnętrzny przez bibliotekę.

5.1.5 Konfiguracja modułu RTC.

1 RTC_DS1307 r t c ;

Rysunek 5.4: Definicja RTC.

Na rysunku 5.4 przedstawiono fragment kodu odpowiedzialny za definicję obiektu rtc, który jest instancją klasy RTC_DS1307 z biblioteki RTClib [1]. Obiekt ten reprezentuje moduł zegara czasu rzeczywistego (RTC) i odpowiada za synchronizację systemu z aktualnym czasem kalendarzowym.

Zachowanie w przypadku błędu

Jeżeli komunikacja z modułem RTC nie zostanie nawiązana, program wygeneruje ostrzeżenie o błędzie, co umożliwia użytkownikowi szybką identyfikację problemu.

### 5.1.6 Definicje trybów pracy i źródeł wartości

1 | enum Mode { AUTOMATIC, MANUAL };
2 | Mode c u r r e n tM o d e = AUTOMATIC; // Domy ślny tryb

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

Rysunek 5.5: Typ wyliczeniowy ENUM.

Opis trybów pracy

Rysunek 5.5 pokazuje dwie możliwości działania systemu, które zostały zdefiniowane za pomocą wyliczeniowego typu danych enum Mode:

- AUTOMATIC - Tryb automatyczny, w którym zadajnik reguluje napięcie wyjściowe na podstawie sygnałów z czujników i zaimplementowanej logiki sterowania.

Rozdział 5. Software

- MANUAL - Tryb ręczny, w którym użytkownik może samodzielnie ustawiać napięcie wyjściowe przy pomocy encodera.

Domyślny tryb systemu ustawiono jako AUTOMATIC, co pozwala na rozpoczęcie pracy zadajnika z pełną funkcjonalnością automatycznej regulacji.

Opis źródeł wartości wejściowych

Zmienna wyliczeniowa ValueSource definiuje dwa możliwe źródła wartości wejściowych:

- BMS_INPUT - Wartości wejściowe są pobierane z encodera jako nastawa BMS. Ten tryb jest stosowany, gdy nie posiadamy sygnału wejściowego z BMS.
- BMS_ENCODER - Wartości wejściowe są ustawiane ręcznie za pomocą encodera. Tryb ten jest aktywowany, gdy sygnał z BMS jest niedostępny i użytkownik chce wymusić priorytet.

Domyślnym źródłem wartości wejściowych jest BMS_INPUT, co odzwierciedla priorytet, na sygnał wejściowy z BMS.

5.1.7 Funkcja korekty offsetu napięcia.

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

}
return v o l t a g e ; // Bez korekcji poza zakresem

}

Rysunek 5.6: Korekta offsetu napięcia dla wejść zadajnika.

Paweł Krutak

Opis funkcji.

Funkcja applyOffsetCorrection() została przedstawiona na rysunku 5.6, jest odpowiedzialna za wprowadzenie korekty offsetu dla wartości napięcia wejściowego w zależności od jego zakresu. Korekta ta pozwala na precyzyjne dopasowanie sygnału pomiarowego do oczekiwanego zakresu pracy, eliminując błędy wynikające z tolerancji sprzętowej.

Zasada działania.

Funkcja przyjmuje pojedynczy parametr voltage typu float reprezentujący napięcie wejściowe, a następnie:

- Sprawdza, do którego zakresu należy wartość napięcia.
- Wprowadza odpowiednią korektę offsetu w zależności od przedziału.
- Zwraca skorygowaną wartość napięcia.

Znaczenie dla projektu.

Korekta offsetu jest istotna w celu poprawy niedoskonałości sprzętowych, takich jak:

- Błędy pomiarowe przetwornika analogowo-cyfrowego (ADC),
- Tolerancje sprzętu, np. różnice w czujnikach napięcia,
- Nieliniowości w sygnałach wejściowych.

Dzięki zastosowaniu tej funkcji możliwe jest uzyskanie bardziej stabilnych i precyzyjnych wyników pomiarowych, co przekłada się na lepszą jakość regulacji w systemie sterowania pompą.

5.1.8 Funkcja interpolacji kawałkowej.

Funkcję interpolateVoltage() pokazana na rysunku 5.7 realizuje interpolację kawałkową, przeliczając wartość odczytaną z przetwornika analogowo-cyfrowego (ADC)
[23] na odpowiadające jej napięcie woltowe. Wartości graniczne (ADC_POINTS) oraz odpowiadające im napięcia referencyjne (VREFS) definiują przedziały, w których funkcja zwraca wynik.

Opis działania.

- Przeszukiwanie przedziałów: Pętla for analizuje kolejne przedziały zdefiniowane przez ADC_POINTS. Jeżeli wartość adc_reading mieści się w danym przedziale, to następuje obliczenie współczynnika skalowania (slope).

Rozdział 5. Software

1 | // Funkcja interpolacji kawa ł kowej
2 | float i n t e r p o l a t e V o l t a g e ( u i n t 3 2 _ t a d c _ r e a d i n g ) {
3 | for (int i = 0; i < 3; i ++) {
4 | if ( a d c _ r e a d i n g >= ADC_POINTS[ i ] && a d c _ r e a d i n g <= ADC_POINTS
[ i + 1]) {
5 | // Oblicz wsp ół czynnik skalowania w bie żącym zakresie
6 | float s l o p e = (VREFS[ i + 1] - VREFS[ i ]) / (ADC_POINTS[ i +
1] - ADC_POINTS[ i ]) ;
7 | return VREFS[ i ] + s l o p e * ( a d c _ r e a d i n g - ADC_POINTS[ i ]) ;
8 | }
9 | }
10 | // Zabezpieczenie przed warto ś ciami poza zakresem
11 | return a d c _ r e a d i n g < ADC_POINTS[0] ? VREFS[0] : VREFS[3];
12 | }

Rysunek 5.7: Funkcja interpolacji kawałkowej.

- Obliczanie napięcia: Interpolacja jest realizowana według wzoru (7):

result = VREFS[i] + slope · (adc_reading − ADC_POINTS[i]) (7),

gdzie slope to nachylenie linii interpolacyjnej w bieżącym przedziale.

- Zabezpieczenie przed wartościami poza zakresem: Jeśli adc_reading znajduje się poza zakresem określonym przez ADC_POINTS, zwracana jest wartość skrajna z VREFS.

Znaczenie dla projektu

Interpolacja kawałkowa pozwala na precyzyjne przeliczenie wartości z ADC na napięcie woltowe, eliminując nieliniowości i niedokładności przetwornika. Dzięki temu funkcja umożliwia dokładne odwzorowanie sygnałów analogowych w zakresie zdefiniowanym przez użytkownika, co jest kluczowe dla poprawnego działania systemu sterowania w projekcie.

5.1.9 Funkcja wygładzania eksponencjalnego.

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

Rysunek 5.8: Funkcja wygładzania eksponencjalnego.

Paweł Krutak

Opis funkcji

Funkcja applyExponentialSmoothing(), którą przedstawia rysunek 5.8, realizuje wygładzanie eksponencjalne, które pozwala na eliminację szumu z danych pomiarowych. Wygładzanie eksponencjalne nadaje większą wagę nowszym wartościom, jednocześnie zachowując część informacji z poprzednich pomiarów. Funkcja ta jest powszechnie stosowana w przetwarzaniu sygnałów i danych pomiarowych.

Parametry wejściowe

- currentValue - Aktualna wartość pomiaru (float), - napięcie odczytane z wejścia.
- previousValue - Poprzednia wygładzona wartość (float), przechowywana w systemie z poprzedniego kroku obliczeń.
- alpha — Współczynnik wygładzania (float), którego wartość mieści się w zakresie od 0 do 1. Określa on stopień wagi nadawanej nowym pomiarom:

– Dla wartości alpha bliskiej 1 większy nacisk kładzie się na bieżące dane, co prowadzi do szybszej reakcji na zmiany.

– Dla wartości alpha bliskiej 0 większą wagę mają dane historyczne, co prowadzi do bardziej stabilnego, ale wolniejszego dostosowywania.

Działanie funkcji

Funkcja oblicza wygładzoną wartość na podstawie poniższego równania (8):

Wynik = α · currentValue + (1 − α) · previousValue (8),

- Składnik α· currentValue odpowiada za wprowadzenie bieżących danych do wyniku.
- Składnik (1 − α) · previousValue uwzględnia wpływ poprzednich wartości.

Znaczenie dla projektu

W | projekcie | elektronicznego | optymalizatora | pompy | funkcja
applyExponentialSmoothing() odgrywa ważną rolę w przetwarzaniu danych z czujników, takich jak:
- Wygładzanie pomiarów napięcia (położenia kuli zaworu EV (pin VP) i BMS (pin VN)), które mogą być zaszumione z powodu niedoskonałości przetwornika ADC lub dokładności przetwarzania napięcia z zakresu 0 − 10 V na 0 − 3.3 V.
- Poprawa stabilności algorytmów sterowania poprzez redukcję wahań w sygnałach wejściowych.

Rozdział 5. Software

Zalety stosowania wygładzania eksponencjalnego

- Prosta implementacja i niski koszt obliczeniowy.
- Efektywne tłumienie szumów przy zachowaniu reaktywności na zmiany w sygnałach wejściowych.
- Możliwość dostosowania do różnych aplikacji dzięki regulowanemu parametrowi

alpha.

Funkcja ta jest kluczowym elementem systemu, zapewniającym dokładne i stabilne dane do dalszego przetwarzania.

5.1.10 Funkcja zmiany trybu pracy systemu.

1 | // Funkcja zmiany trybu
2 | void changeMode () {
3 | c u r r e n tM o d e = ( c u r r e n tM o d e == AUTOMATIC) ? MANUAL : AUTOMATIC;
4 | }

Rysunek 5.9: Funkcja zmiany trybu pracy systemu.

Opis funkcji

Funkcja changeMode() znajdująca się na rysunku 5.9, odpowiada za przełączanie trybu pracy systemu pomiędzy trybem automatycznym (AUTOMATIC) a ręcznym (MANUAL). Realizuje to w prosty sposób za pomocą operatora warunkowego (ternary

operator).

Paweł Krutak

5.1.11 Funkcja obsługi encodera BMS.

1 | // Funkcja obs ługi encodera BMS
2 | void IRAM_ATTR ha n dl eE n c o d e rBM S () {
3 | int c u r r e n t S t a t e C L K = d i g i t a l R e a d (CLK_BMS) ;
4 | if ( c u r r e n t S t a t e C L K != la s tS ta teCLK_BMS && c u r r e n t S t a t e C L K ==
| HIGH) {
5 | if ( d i g i t a l R e a d (DT_BMS) != c u r r e n t S t a t e C L K ) {
6 | if ( c o u n t e r_ bm s < 100) c o u n t e r_ bm s ++;
7 | } else {
8 | if ( c o u n t e r_ bm s > 0) c o u n t e r_ bm s - -;
9 | }
10 | bm s_ val u e = c o u n t e r_ bm s * 0.1;
11 | }
12 | la s tS ta teCLK_BMS = c u r r e n t S t a t e C L K ;

Rysunek 5.10: Funkcja obsługi encodera BMS.

Funkcja handleEncoderBMS() przedstawiona na rysunku 5.10 obsługuje sygnały z encodera odpowiedzialnego za sterowanie systemem BMS. W przerwaniu sprzętowym (IRAM_ATTR) odczytywany jest aktualny stan pinu zegarowego (CLK_BMS). Przy każdej zmianie stanu na HIGH, funkcja analizuje kierunek obrotu encodera, porównując stan pinu danych (DT_BMS) z bieżącym stanem zegara. Wartość licznika counter_bms jest odpowiednio zwiększana lub zmniejszana w zakresie od 0 do 100. Obliczona wartość bms_value, jako iloczyn counter_bms i współczynnika 0.1, odzwierciedla ustawienie encodera w jednostkach napięcia dla zakresu 0 − 10 V. Funkcja umożliwia płynną regulację parametrów wejściowych systemu BMS w czasie rzeczywistym.

5.1.12 Funkcja obsługi encodera VOLT.

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

Rysunek 5.11: Funkcja obsługi encodera VOLT.

Rozdział 5. Software

Funkcja handleEncoderVOLT(), która pokazuje rysunek 5.11, działa w sposób analogiczny do funkcji handleEncoderBMS, jednak jej zadaniem jest obsługa encodera odpowiedzialnego za ustawienie napięcia wyjściowego w zakresie 0 − 10 V. Funkcja jest używana w trybie MANUAL, umożliwiając użytkownikowi ręczną regulację napięcia wyjściowego zadajnika.

5.1.13 Funkcja obsługi encodera TIME.

int v a l u e s _ t i m e [] = {5 , 15 , 30 , 45 , 60}; // Warto ści czasowe dla enodera TIME

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

}
} else {
if ( i n d e x _ t i m e > 0) { i n d e x _ t i m e - -;

}

}

}
la s t S ta t eC LK_TIME = c u r r e n t S t a t e C L K ;

}

Rysunek 5.12: Funkcja obsługi encodera TIME.

Funkcja handleEncoderTIME(), którą prezentuje rysunek5.12, obsługuje encoder do nastawy jednego z predefiniowanych interwałów czasowych zapisanych w tablicy values_time, która zawiera wartości: {5, 15, 30, 45, 60} sekund. Funkcja działa w przerwaniu sprzętowym (IRAM_ATTR), co zapewnia szybkie reagowanie na sygnały z encodera. Odczytywany jest stan pinu zegarowego CLK_TIME. W momencie zmiany stanu na HIGH analizowany jest kierunek obrotu enodera na podstawie stanu pinu

DT_TIME.
Jeśli encoder obraca się w jednym kierunku, indeks index_time jest zwiększany o 1
(do | maksymalnej | wartości | odpowiadającej | ostatniemu | elementowi | tablicy).
W przeciwnym kierunku index_time jest zmniejszany o 1 (do minimalnej wartości 0). Wybrany interwał czasowy odpowiada wartości w tablicy values_time[index_time], co umożliwia dynamiczne ustawienie czasu regulacji w trybie automatycznym. Wybrany

Paweł Krutak

czas można zapisać wzorem (9):

time_interval = values_time[index_time] (9),

gdzie time_interval to aktualny czas w sekundach, zależny od pozycji encodera.

### 5.1.14 Inicjalizacja interfejsów komunikacyjnych i urządzeń

### peryferyjnych

1 | S e r i a l . b e g i n (115200) ;
2 | Wi re . b e g i n (21 , 22) ;
3 | u 8 g 2 . b e g i n () ;

Rysunek 5.13: Inicjalizacja komunikacji.

Na rysunku 5.13 zamieszczono fragment kodu odpowiadający za uruchomienie podstawowych interfejsów komunikacyjnych i urządzeń peryferyjnych. Funkcja Serial.begin(115200) inicjalizuje port szeregowy UART z prędkością 115200 bitów na sekundę, co umożliwia komunikację z komputerem w celach diagnostycznych i debugowania. Funkcja Wire.begin(21, 22) [28] inicjalizuje magistralę I²C, przypisując piny 21 (SDA) i 22 (SCL) do komunikacji z urządzeniami peryferyjnymi, takimi jak moduł RTC i wyświetlacz OLED. Funkcja u8g2.begin() uruchamia bibliotekę U8g2lib [16], umożliwiając obsługę wyświetlacza OLED.

5.1.15 Sprawdzenie obecności modułu RTC.

1 | if (! r t c . b e g i n () ) {
2 | S e r i a l . p r i n t l n ("RTC nie znaleziono !") ;
3 | while (1) ;
4 | }

Rysunek 5.14: Sprawdzenie poprawności działania modułu RTC.

Powyższy fragment kodu przedstawiony na rysunku 5.14 weryfikuje, czy moduł zegara czasu rzeczywistego (RTC) został poprawnie zainicjalizowany. Funkcja rtc.begin() [1] próbuje uruchomić komunikację z modułem RTC. Jeśli moduł nie zostanie wykryty, na porcie szeregowym wyświetlany jest komunikat diagnostyczny "RTC nie znaleziono!", a program wchodzi w nieskończoną pętlę while(1). Taka konstrukcja pozwala zatrzymać działanie systemu w przypadku krytycznego błędu, umożliwiając użytkownikowi zidentyfikowanie problemu i podjęcie działań naprawczych.

Rozdział 5. Software

5.1.16 Synchronizacja czasu modułu RTC.

1 | if (! r t c . i s r u n n i n g () ) {
2 | r t c . a d j u s t ( Da teTime (F(__DATE__) , F(__TIME__) ) ) ;
3 | }

Rysunek 5.15: Synchronizacja czasu modułu RTC.

Rysunek 5.15 prezentuje fragment kodu, który sprawdza, czy moduł zegara czasu rzeczywistego (RTC) jest aktywny i posiada ustawiony czas. Funkcja rtc.isrunning()
[1] weryfikuje, czy moduł RTC działa poprawnie. Jeśli czas nie został wcześniej ustawiony (np. po pierwszym uruchomieniu lub wymianie baterii podtrzymującej), funkcja rtc.adjust() synchronizuje zegar modułu z czasem kompilacji programu. W tym celu wykorzystywane są makra __DATE__ i __TIME__, które przechowują datę i godzinę kompilacji kodu [1].
Ten mechanizm zapewnia, że moduł RTC zawsze posiada poprawne dane czasowe, co jest kluczowe dla wyświetlania aktualnego czasu oraz realizacji zadań związanych z synchronizacją w systemie, takich jak interwały regulacji w trybie automatycznym.

5.1.17 Inicjalizacja wyświetlacza OLED i komunikat powitalny.

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

Rysunek 5.16: Inicjalizacja wyświetlacza OLED

Powyższy fragment kodu pokazany na rysunku 5.16, odpowiada za przygotowanie wyświetlacza OLED do pracy oraz wyświetlenie komunikatu powitalnego. Funkcja u8g2.clearBuffer() [16] czyści bufor wyświetlacza, umożliwiając rozpoczęcie
renderowania | nowej | zawartości. | Następnie | funkcja
u8g2.setFont(u8g2_font_ncenB08_tr) [16] ustawia czcionkę ncenB08_tr, która jest stylizowaną czcionką o rozmiarze 8 punktów. Tekst "Start programu!" jest rysowany na ekranie przy pomocy funkcji u8g2.drawStr() [16], zaczynając od pozycji (0, 10) na ekranie. Funkcja u8g2.sendBuffer() [16] przesyła zawartość bufora do wyświetlacza, dzięki czemu tekst staje się widoczny, a delay(2000) wprowadza 2-sekundowe opóźnienie, umożliwiając użytkownikowi zapoznanie się z komunikatem. Fragment ten pełni funkcję informacyjną, sygnalizując użytkownikowi poprawne uruchomienie programu.

Paweł Krutak

5.1.18 Konfiguracja trybów pracy pinów mikrokontrolera.

1 | pinM ode (CLK_BMS, INPUT_PULLUP) ;
2 | pinM ode (DT_BMS, INPUT_PULLUP) ;
3 | pinM ode (CLK_VOLT, INPUT_PULLUP) ;
4 | pinM ode (DT_VOLT, INPUT_PULLUP) ;
5 | pinM ode (CLK_TIME, INPUT_PULLUP) ;
6 | pinM ode (DT_TIME, INPUT_PULLUP) ;
7 | pinM ode (BUTTON_PIN, INPUT_PULLUP) ;
8 | pinM ode (ANALOG_OUT, OUTPUT) ;
9 | pinM ode (ENCODER_BUTTON_PIN, INPUT_PULLUP) ;
10 | pinM ode (DIGITAL_OUT, OUTPUT) ;
11 | pinM ode (DIGITAL_BMS, OUTPUT) ;
12 | pinM ode (DIGITAL_EV, OUTPUT) ;

Rysunek 5.17: Konfiguracja trybów pracy pinów mikrokontrolera.

Powyższy fragment kodu przedstawiony na rysunku 5.17, konfiguruje tryby pracy pinów mikrokontrolera ESP32 przy użyciu funkcji pinMode() [27], dostosowując je do wymagań projektu. Piny wejściowe (INPUT_PULLUP) obsługują sygnały zegarowe

| (CLK_BMS, CLK_VOLT, CLK_TIME), dane z encoderów (DT_BMS, DT_VOLT, DT_TIME), oraz
przyciski (BUTTON_PIN, ENCODER_BUTTON_PIN), wykorzystując wewnętrzne rezystory podciągające. Piny wyjściowe (OUTPUT) sterują sygnałami dla urządzeń peryferyjnych, takich jak pompa (ANALOG_OUT) i diody sygnalizacyjne (DIGITAL_OUT, DIGITAL_BMS, DIGITAL_EV). Taka konfiguracja zapewnia poprawne odczyty danych wejściowych oraz umożliwia generowanie sygnałów sterujących, co jest kluczowe dla prawidłowej współpracy mikrokontrolera z urządzeniami peryferyjnymi i elementem wykonawczym w projekcie [25].

5.1.19 Inicjalizacja stanów początkowych encoderów.

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

Rysunek 5.18: Inicjalizacja stanów początkowych encoderów.

Rysunek 5.18 prezentuje fragment kodu, który inicjalizuje początkowe stany sygnałów zegarowych dla encoderów używanych w projekcie. Każda zmienna
| (lastStateCLK_BMS, lastStateCLK_VOLT, lastStateCLK_TIME) przechowuje wartość
odczytaną z odpowiedniego pinu wejściowego (CLK_BMS, CLK_VOLT, CLK_TIME) za pomocą funkcji digitalRead() [27]. Operacja ta pozwala na zapamiętanie aktualnego stanu sygnału zegarowego, co jest niezbędne do poprawnego określania kierunku i liczby

Rozdział 5. Software

impulsów obrotowych encodera w dalszej części programu. Dzięki tej inicjalizacji system ma punkt odniesienia dla analizy zmian sygnału zegarowego, co umożliwia precyzyjne sterowanie różnymi funkcjami, takimi jak ustawienia BMS, napięcia wyjściowego i interwałów czasowych.

5.1.20 Konfiguracja przerwań dla encoderów.

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

Rysunek 5.19: Konfiguracja przerwań dla encoderów.

Rysunek 5.19 opisuje fragment kodu, który konfiguruje przerwania dla pinów zegarowych encoderów, co pozwala na obsługę sygnałów w czasie rzeczywistym. Funkcja attachInterrupt() [27] przypisuje przerwanie do każdego pinu wejściowego (CLK_BMS, CLK_VOLT, CLK_TIME), wskazując funkcję obsługującą odpowiedni (handleEncoderBMS,

| handleEncoderVOLT, handleEncoderTIME) oraz typ zdarzenia CHANGE, które aktywuje
przerwanie przy każdej zmianie stanu sygnału (z HIGH na LOW lub odwrotnie). Dzięki temu encodery mogą być obsługiwane niezależnie od głównej pętli programu, co zapewnia szybką i precyzyjną reakcję systemu na zmiany sygnałów. Konfiguracja przerwań jest kluczowa dla precyzyjnego sterowania parametrami BMS, napięciem wyjściowym oraz interwałami czasowymi.

5.1.21 Inicjalizacja początkowego stanu wyjściowego pompy.

1 | // Pocz ą tkowy stan (100% mocy pompy )
2 | if ( f i r s t R u n ) {
3 | o u t p u t V o l t a g e = 10.0; // Ustawienie na maksymaln ą moc
4 | f i r s t R u n = f a l s e ;
5 | }

Rysunek 5.20: Inicjalizacja początkowego stanu wyjściowego pompy

Powyższy fragment kodu zamieszczony na rysunku 5.20 ustawia początkowy stan napięcia wyjściowego sterującego pompą na maksymalną wartość 10.0 V, co odpowiada pracy pompy na pełnej mocy. Mechanizm ten jest kontrolowany za pomocą flagi logicznej firstRun, która przy pierwszym uruchomieniu programu ma wartość true. Po ustawieniu maksymalnego napięcia, zmienna firstRun jest ustawiana na false, aby

Paweł Krutak

zapobiec wielokrotnemu wykonywaniu tego bloku kodu. Inicjalizacja początkowego stanu zapewnia, że pompa rozpoczyna pracę z pełną mocą, a następnie przechodzi do normalnego sterowania zgodnie z dalszą logiką programu.

5.1.22 | Obsługa | przycisku | z | eliminacją | drgań | styków
(debouncing).

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

}

}

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

Rysunek 5.21: Obsługa przycisku z eliminacją drgań styków (debouncing).

Powyższy fragment kodu przedstawiony na rysunku 5.21, obsługuje przycisk z mechanizmem eliminacji drgań styków (debouncing). Drgania styków to naturalne zakłócenia występujące podczas mechanicznego wciskania lub zwalniania przycisków, które powodują wielokrotne, krótkotrwałe zmiany sygnału. Mechanizm debouncing wprowadza opóźnienie czasowe, dzięki któremu system rejestruje jedynie stabilne zmiany stanu przycisku. Po odczytaniu bieżącego stanu przycisku (digitalRead(BUTTON_PIN)) [27], kod sprawdza, czy stan różni się od poprzedniego (lastButtonState1). W przypadku zmiany, aktualizowany jest czas zmiany stanu za pomocą millis() [27], a następnie, jeśli od ostatniej zmiany minęło więcej niż debounceDelay1, stan przycisku jest aktualizowany. Jeśli nowy stan to LOW (zbocze opadające), wywoływana jest funkcja changeMode(), zmieniająca tryb pracy systemu. Mechanizm ten zapewnia stabilność działania przycisku, eliminując fałszywe odczyty, co jest kluczowe w systemach automatyki wymagających niezawodnej obsługi wejść.

Rozdział 5. Software

### 5.1.23 Odczyt, przetwarzanie i skalowanie napięć z pinów: VP

i VN.

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

// Skalowanie napi ęć do 0 -10 V
float s c a l e d V P = f i l t e r e d V P * (10.0 / 3.3) ;
float s c a l e dV N = f i l t e r e d V N * (10.0 / 3.3) ;

Rysunek 5.22: Odczyt, przetwarzanie i skalowanie napięć odczytanych z pinów: VP i VN.

Powyższy fragment kod pokazany na rysunku 5.22, realizuje odczyt, przetwarzanie i skalowanie wartości napięć z pinów analogowych VP_PIN i VN_PIN. Funkcja analogRead() [27] odczytuje surowe dane z przetwornika analogowo-cyfrowego (ADC), które następnie są przetwarzane przez interpolateVoltage() w celu przeliczenia na wartości napięcia oraz przez applyOffsetCorrection() dla korekcji offsetu. Przetworzone napięcia są poddawane wygładzaniu eksponencjalnemu przy użyciu applyExponentialSmoothing(), co pozwala na redukcję szumów. Ostatecznie, wygładzone wartości są skalowane z zakresu 0 − 3.3 V na 0 − 10 V poprzez przemnożenie przez współczynnik 10.0
3.3

. Przetworzone i przeskalowane wartości (scaledVP i scaledVN) zapewniają dokładne i stabilne dane wejściowe dla dalszych obliczeń w zadajniku.

5.1.24 Logika regulacji w trybie automatycznym.

Fragment kodu, który znajduje się na rysunku 5.23, implementuje logikę regulacji w trybie automatycznym, w którym napięcie wyjściowe outputVoltage jest sterowane na podstawie odczytów z różnych źródeł danych. Interwał regulacji (adjustmentInterval) jest ustawiany w zależności od wartości wybranej za pomocą encodera. Jeśli od ostatniej regulacji upłynął czas dłuższy niż ustawiony interwał, system analizuje dane wejściowe. W pierwszej kolejności uwzględniany jest sygnał z BMS (scaledVN), jeśli jego wartość

Paweł Krutak

przekracza 0 i tryb pracy to BMS_INPUT. W przypadku braku takiego sygnału, priorytet ma wartość z encodera (bms_value) w trybie BMS_ENCODER. Jeżeli żaden z tych warunków nie jest spełniony to regulacja odbywa się na podstawie informacji o położeniu kuli zaworu EV (scaledVP) w odniesieniu do outputVoltage. Następnie wartość napięcia jest przeliczana na sygnał PWM i przesyłana do wyjścia ANALOG_OUT za pomocą analogWrite() [27], co pozwala na sterowanie urządzeniami wykonawczymi w zakresie 0–10V.

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

}

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

}

Rysunek 5.23: Logika regulacji w trybie automatycznym.

Rozdział 5. Software

5.1.25 Logika regulacji w trybie ręcznym.

1 | if ( c u r r e n tM o d e == MANUAL) {
2 | int pwmValue = ( v o l t _ v a l u e / 10.0) * 255;
3 | a n a l o gW r i t e (ANALOG_OUT, pwmValue ) ;
4 | }

Rysunek 5.24: Logika regulacji w trybie ręcznym.

Rysunek 5.24 obejmuje fragment kodu, który implementuje logikę sterowania w trybie ręcznym (MANUAL). Gdy system znajduje się w tym trybie, wartość napięcia wyjściowego (volt_value) jest bezpośrednio przeliczana na sygnał PWM w zakresie 0–255 przy pomocy równania (10):

pwmValue =

volt_value
10.0

!
- 255 (10),

gdzie volt_value reprezentuje napięcie wyjściowe w zakresie od 0 V do 10 V. Obliczona wartość PWM jest następnie przesyłana na wyjście ANALOG_OUT przy użyciu funkcji analogWrite() [27]. Logika ta pozwala użytkownikowi ręcznie kontrolować napięcie wyjściowe za pomocą encodera, bez interwencji automatycznego systemu regulacji, co zapewnia elastyczność w dostosowywaniu parametrów pracy do indywidualnych potrzeb.

5.1.26 Obsługa diod sygnalizacyjnych.

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

Rysunek 5.25: Obsługa diod sygnalizacyjnych.

Rysunek 5.25 przedstawia fragment kodu do sterowania diodami sygnalizacyjnymi, które wizualizują stan kluczowych parametrów systemu. Dioda DIGITAL_OUT wskazuje aktywność wyjścia zadajnika - jest włączana (HIGH), gdy wartość napięcia outputVoltage przekracza 0.1 V, co sygnalizuje, że zadajnik dostarcza napięcie. Dioda DIGITAL_BMS informuje o obecności sygnału z systemu BMS, włączając się, gdy scaledVN jest większe niż 0.1 V. Dioda DIGITAL_EV sygnalizuje aktywność sygnału z zaworu, włączając się, gdy wartość scaledVP przekracza 0.1 V. Mechanizm ten zapewnia użytkownikowi intuicyjną informację o stanie wejść i wyjścia co ułatwia diagnozowanie i monitorowanie pracy urządzenia w czasie rzeczywistym.

Paweł Krutak

5.1.27 Wyświetlanie informacji na wyświetlaczu OLED.

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

Rysunek 5.26: Wyświetlanie informacji na wyświetlaczu OLED.

Powyższy fragment kodu pokazany na rysunku 5.26 odpowiada za wyświetlanie kluczowych informacji o stanie systemu na wyświetlaczu OLED, które możemy zobaczyć na rysunku 5.27b. Wykorzystuje obiekt u8g2 z biblioteki U8g2lib [16], który pozwala na renderowanie tekstu na buforze graficznym, a następnie przesyła zawartości do wyświetlacza za pomocą u8g2.sendBuffer() [16].

Opis działania

- Czas rzeczywisty: Funkcja rtc.now() pobiera aktualny czas z modułu RTC, a u8g2.printf() [16] wyświetla go w formacie hh:mm:ss na pierwszej linii.
- Tryb pracy: Na drugiej linii wyświetlany jest aktualny tryb pracy systemu, który zależy od zmiennej currentMode (AUTO lub MANUAL).
- Napięcia: Na trzeciej linii wyświetlane są napięcia scaledVP i scaledVN reprezentujące wartości odczytane z wejść.

Rozdział 5. Software

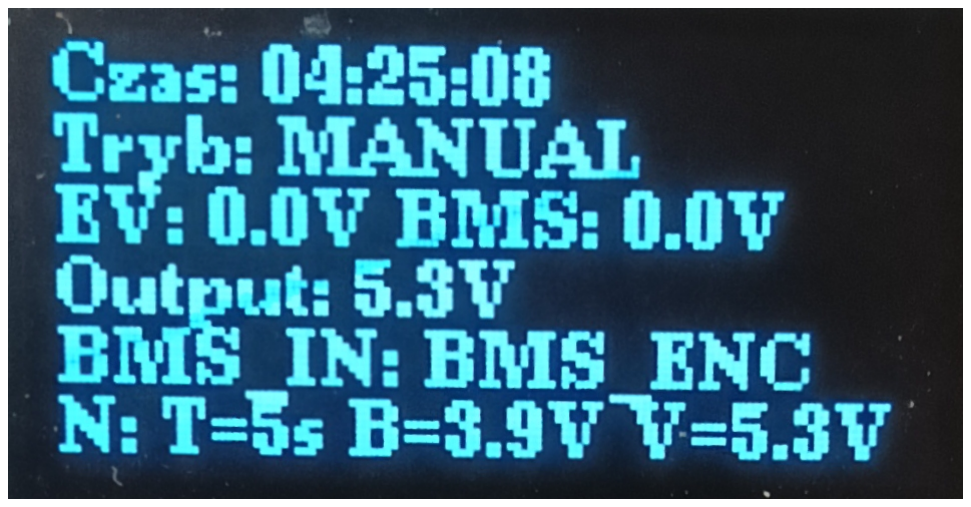
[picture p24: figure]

(a) Wyświetlanie na wyświetlaczu OLED w trybie MANUAL.
(b) Wyświetlanie na wyświetlaczu OLED w trybie AUTO.

Rysunek 5.27: Wyświetlanie informacji na wyświetlaczu OLED.

- Wyjście: Na czwartej linii wyświetlane jest napięcie wyjściowe outputVoltage w trybie automatycznym lub volt_value w trybie ręcznym.
- Źródło BMS: Na piątej linii wskazane jest aktualne źródło danych BMS

(BMS_INPUT lub BMS_ENC).

- Parametry: Ostatnia linia wyświetla parametry regulacji, takie jak interwał czasowy (adjustmentInterval) oraz napięcia bms_value i volt_value.

5.1.28 Realizacja operacji w regularnych odstępach czasu.

Rysunek 5.28 opisuje fragment kodu, który implementuje mechanizm umożliwiający wykonywanie operacji w regularnych odstępach czasu bez blokowania pętli programu. Funkcja millis() [27] zwraca czas w milisekundach od uruchomienia mikrokontrolera, a zmienna interval definiuje żądany odstęp czasowy. Warunek if (currentMillis -previousMillis >= interval) sprawdza, czy od ostatniego wykonania operacji upłynął czas równy lub dłuższy niż interval. Po spełnieniu tego warunku następuje aktualizacja zmiennej previousMillis, zapisującej czas ostatniego wykonania kodu, co umożliwia cykliczne wykonywanie zaplanowanych działań.

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

Rysunek 5.28: Realizacja operacji w regularnych odstępach czasu.

Ten mechanizm jest lepszą alternatywą niż funkcja delay() [27], ponieważ te procesy mogą działać równolegle. Oraz jest kluczowy w systemach czasu rzeczywistego, takich jak zadajniki automatyki, gdzie istotne jest wykonywanie zadań w regularnych

Paweł Krutak

odstępach czasu, np. aktualizacja wyświetlacza OLED, monitorowanie danych wejściowych czy sterowanie urządzeniami peryferyjnymi.

5.2 Podsumowanie.

Implementacja oprogramowania zapewnia modułowość, elastyczność oraz wysoką precyzję regulacji pracy pompy, co spełnia założenia projektowe i umożliwia dalsze rozwijanie systemu.

# Rozdział 6

# Weryfikacja i walidacja

## 6.1 Weryfikacja i walidacja

Celem niniejszego rozdziału jest przedstawienie wyników weryfikacji i walidacji układu elektronicznego optymalizatora, które mają na celu potwierdzenie poprawności działania systemu w warunkach rzeczywistych. Proces weryfikacji obejmował szczegółową analizę kluczowych parametrów, takich jak liniowość przetwarzania sygnałów wejściowych i wyjściowego, dokładność pomiarów oraz zgodność wyników z założeniami projektowymi.
Szczególną uwagę poświęcono badaniom liniowości przetwarzania sygnałów przez dzielniki napięć, wzmacniacz operacyjny oraz przetwornik ADC mikrokontrolera ESP32. Przeprowadzono również pomiary napięć referencyjnych i rzeczywistych dla sygnałów wejściowych, a także sygnału wyjściowego, aby dokładnie sprawdzić poprawność działania zaprojektowanego układu.
Przedstawione w tym rozdziale wyniki oraz przeprowadzone analizy umożliwiają ocenę, czy układ spełnia założone wymagania projektowe, a także identyfikację obszarów, które mogą wymagać dalszej pracy.
6.2 | Badanie | liniowości | przetwarzanego | napięcia
z | wejść | i | wyjścia | elektronicznego

optymalizatora.

Podczas wyboru komponentów zadajnika kluczowym elementem było zapewnienie liniowości przetwarzania napięć zarówno na wejściu, jak i na wyjściu układu. Liniowość ta jest niezbędna dla zachowania dokładności działania systemu sterowania, ponieważ wszelkie nieliniowości mogłyby prowadzić do błędnych wyników regulacji i uniemożliwić skuteczną kontrolę pracy pompy. Dlatego przeprowadzono szczegółowe testy obejmujące

Paweł Krutak

badanie wartości dobranych dzielników napięć, wzmacniacza operacyjnego oraz testów liniowości wejść i wyjścia całego układu.

### 6.2.1 Badanie liniowości przetwarzanego napięcia sygnału

wyjściowego ze wzmacniacza.

Proces testowania rozpoczęto od analizy funkcjonalności wzmacniacza operacyjnego LM358P, który jest kluczowym elementem odpowiedzialnym za wzmocnienie sygnału napięciowego wychodzącego z mikrokontrolera esp32. Badanie polegało na zmierzeniu napięcia wejściowego oraz wyjściowego wzmacniacza dla 10 różnych wartości w zakresie 0-10V. Wyniki pomiarów przedstawiono w tabeli 6.1. Dane prezentowane w tabeli 6.1 są zgodne z udokumentowanymi zdjęciami, które są dostępne w załączniku do pracy.

Tabela 6.1: Liniowość napięcia wyjściowego wzmacniacza operacyjnego LM358P.

Pomiar | Napięcie wejściowe [V] | Napięcie wyjściowe [V]
0 | 0.00 | 0.00
1 | 0.24 | 0.72
2 | 0.62 | 1.87
3 | 0.94 | 2.84
4 | 1.18 | 3.57
5 | 1.47 | 4.45
6 | 2.02 | 6.12
7 | 2.35 | 7.12
8 | 2.75 | 8.33
9 | 3.05 | 9.24
10 | 3.30 | 10.00

Wykres pokazany na rysunku 6.1 świadczy o liniowości przekształcania napięcia przez wzmacniacz LM358P w zakresie 0-10V.
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

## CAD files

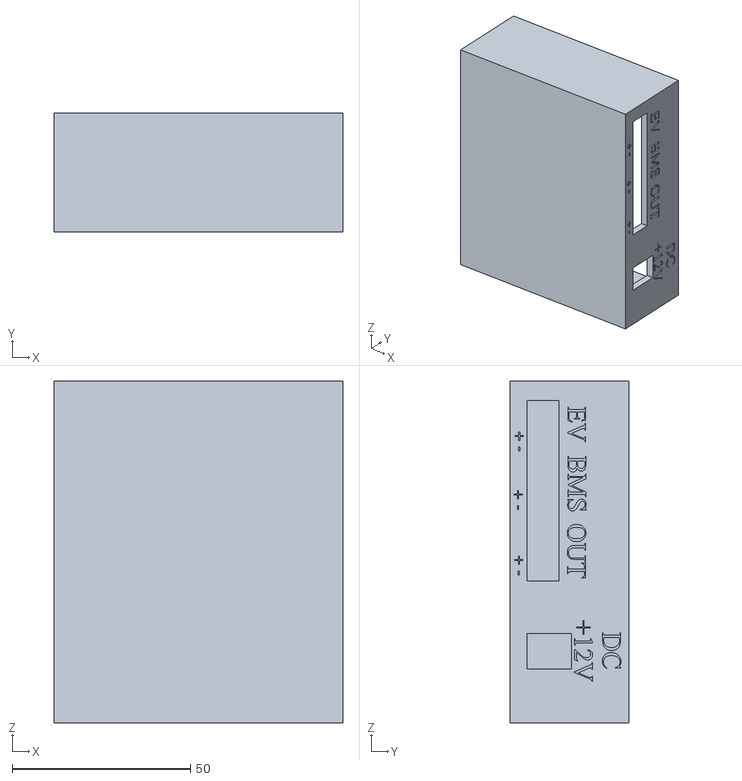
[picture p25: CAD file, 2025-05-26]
BOTTOM1.stl
81.0 x 33.3 x 96.0

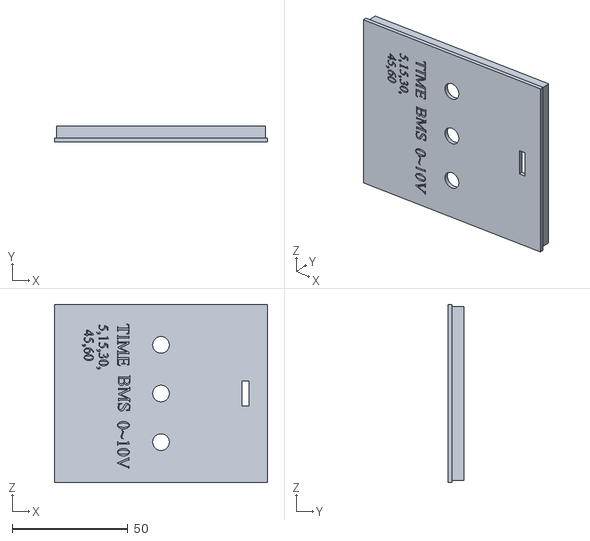
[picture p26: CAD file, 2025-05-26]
TOP1.stl
92.0 x 6.70 x 77.0

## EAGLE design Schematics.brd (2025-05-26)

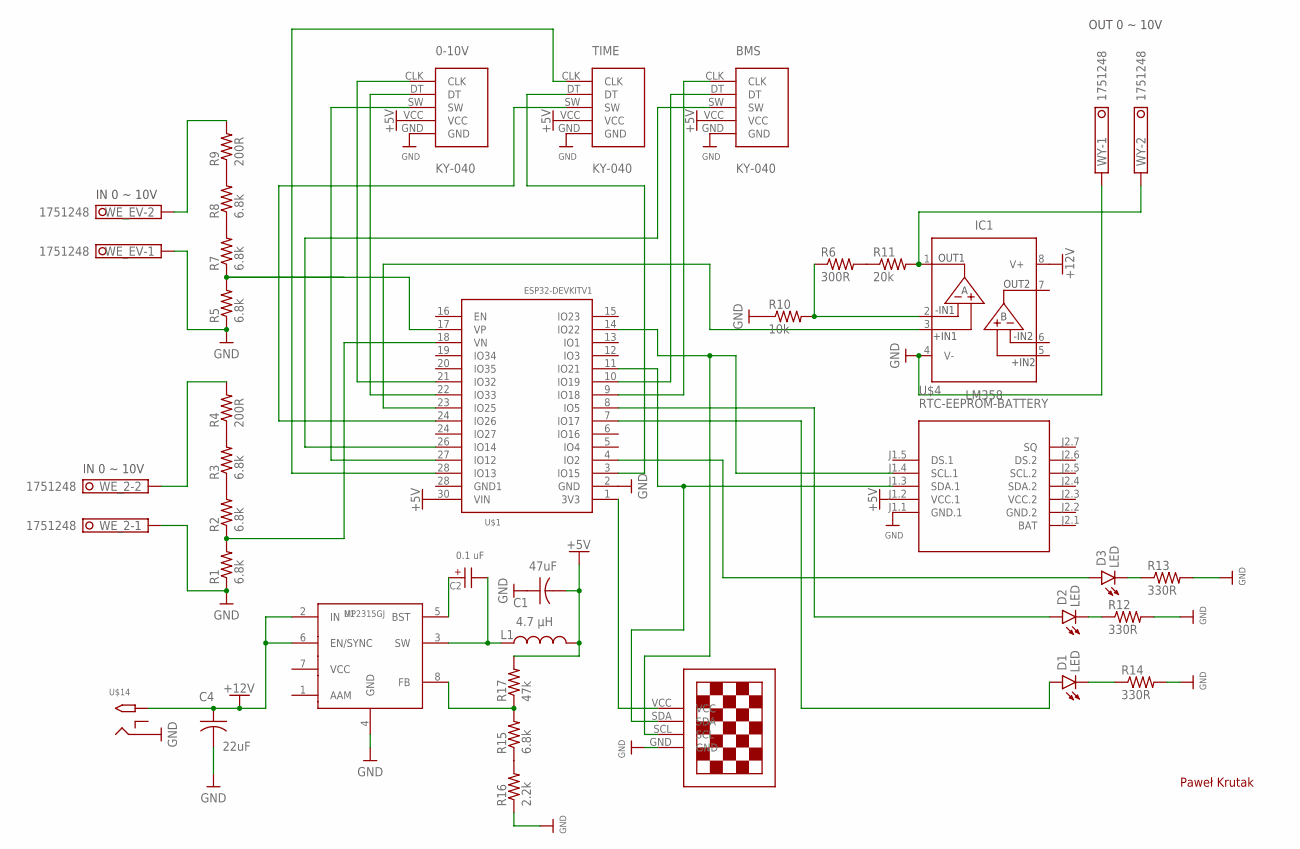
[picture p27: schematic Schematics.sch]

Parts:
0-10V: KY-040; KY-040-PORT
BMS: KY-040; KY-040-PORT
C1: 47uF; CAP_RADIAL_2MM
C2: 0.1 uF; WCAP-ATG5_5X11(DXL)
C4: 22uF; CAP_RADIAL_2MM
D1, D2, D3: LED; LEDRD254W60D565H860B_W90
IC1: LM358; DIP826W53P254L959H508Q8B
L1: 4.7 µH; SRN6045
R1, R2, R3, R5, R7, R8, R15: 6.8k; M0805
R4, R9: 200R; M0805
R6: 300R; M0805
R10: 10k; M0805
R11: 20k; M0805
R12, R13, R14: 330R; M0805
R16: 2.2k; M0805
R17: 47k; M0805
TIME: KY-040; KY-040-PORT
U1: MP2315GJ; SOT-23-8
U$1: ESP32DEVKITV1; ESP32-DEVKITV1
U$4: RTC-EEPROM-BATTERY; RTC_EEPROM_BATTERY
U$8: 13"OLED13"OLED; 1.3"OLED
U$14: 2.1MMJACKTHM; PJ-102A
WE_2: 1751248
WE_EV: 1751248
WY: 1751248

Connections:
+5V: 0-10V.VCC, BMS.VCC, C1.2, L1.2, R17.2, TIME.VCC, U$1.30 (VIN), U$4.J1.2 (VCC.1)
+12V: C4.1, IC1.8 (V+), U1.2 (IN), U1.6 (EN/SYNC), U$14.TIP
GND: 0-10V.GND, BMS.GND, C1.1, C4.2, IC1.4 (V-), R1.1, R5.1, R10.1, R12.2, R13.2, R14.2, R16.1, TIME.GND, U1.4 (GND), U$1.2 (GND), U$4.J1.1 (GND.1), U$8.GND, U$14.RING, WE_2.1, WE_EV.1, WY.1
GND.2: U$4.J2.2 (GND.2)
unnamed: IC1.1 (OUT1), R11.2, WY.2
unnamed: R6.2, R11.1
unnamed: IC1.2 (-IN1), R6.1, R10.2
unnamed: IC1.3 (+IN1), U$1.23 (IO25)
unnamed: R2.2, R3.1
unnamed: R5.2, R7.1, U$1.17 (VP)
unnamed: R4.2, WE_2.2
unnamed: R3.2, R4.1
unnamed: R7.2, R8.1
unnamed: R1.2, R2.1, U$1.18 (VN)
unnamed: R8.2, R9.1
unnamed: U$1.1 (3V3), U$8.VCC
unnamed: U$1.14 (IO22), U$4.J1.4 (SCL.1), U$8.SCL
unnamed: U$1.11 (IO21), U$4.J1.3 (SDA.1), U$8.SDA
unnamed: 0-10V.CLK, U$1.21 (IO32)
unnamed: BMS.CLK, U$1.9 (IO18)
unnamed: BMS.DT, U$1.10 (IO19)
unnamed: 0-10V.DT, U$1.22 (IO33)
unnamed: BMS.SW, U$1.26 (IO14)
unnamed: 0-10V.SW, U$1.27 (IO12)
unnamed: D2.1 (A), U$1.8 (IO5)
unnamed: R15.1, R16.2
unnamed: D1.1 (A), U$1.7 (IO17)
unnamed: R9.2, WE_EV.2
unnamed: D3.2 (C), R13.1
unnamed: D2.2 (C), R12.1
unnamed: D3.1 (A), U$1.4 (IO2)
unnamed: D1.2 (C), R14.1
unnamed: TIME.CLK, U$1.28 (IO13)
unnamed: TIME.DT, U$1.3 (IO15)
unnamed: TIME.SW, U$1.24 (IO27)
unnamed: C2.1 (+), U1.5 (BST)
unnamed: R15.2, R17.1, U1.8 (FB)
unnamed: C2.2 (-), L1.1, U1.3 (SW)
VCC.2: U$4.J2.3 (VCC.2)

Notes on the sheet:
OUT 0 ~ 10V
Paweł Krutak
IN 0 ~ 10V

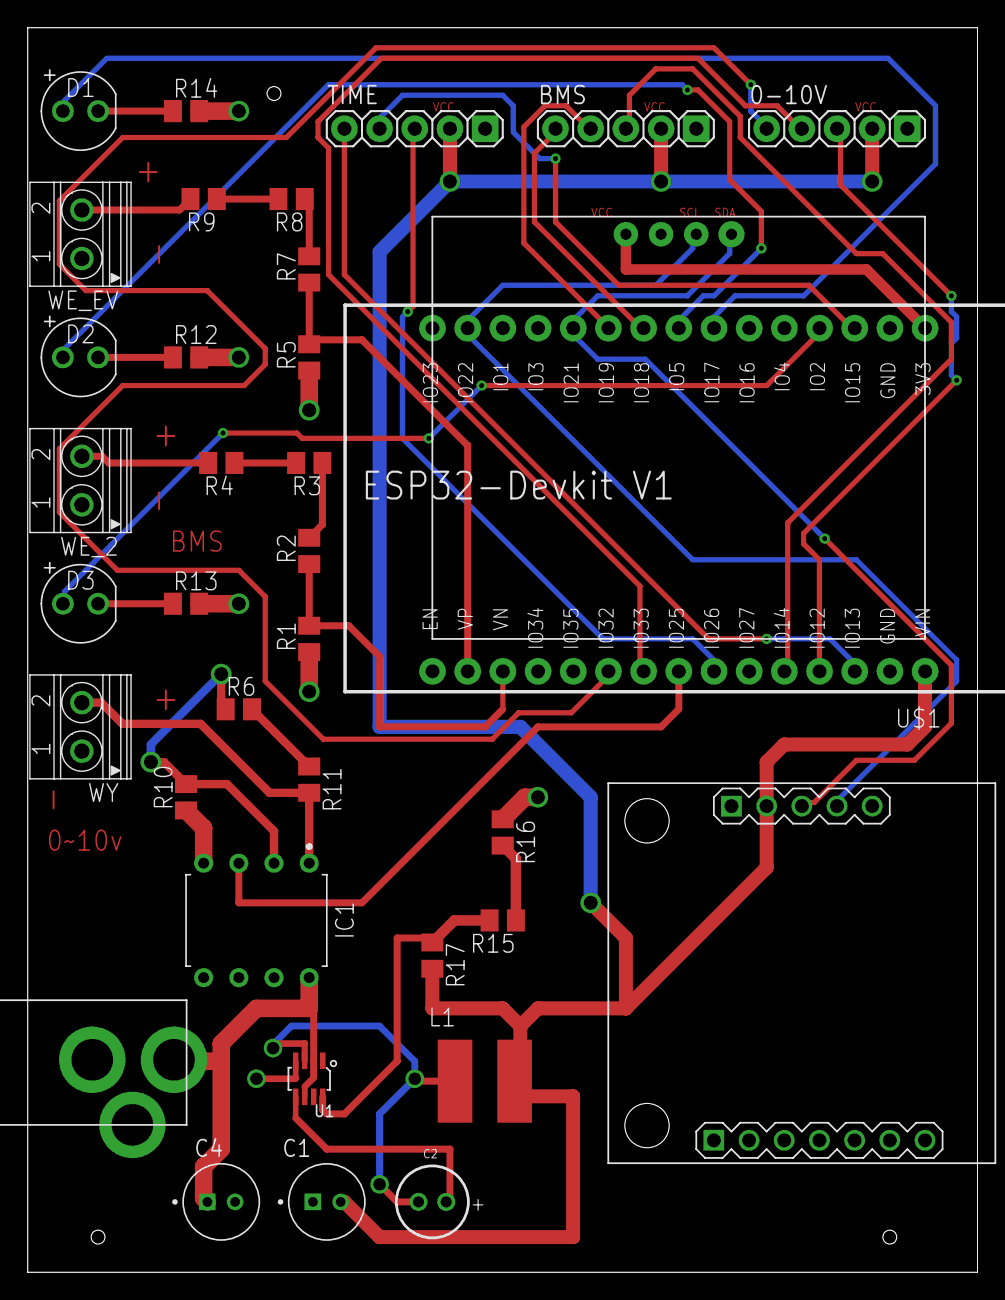
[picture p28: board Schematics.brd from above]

Board: 2 copper layers, 68.6 x 89.8 mm, 36 parts (0 on the bottom side), 37 nets.

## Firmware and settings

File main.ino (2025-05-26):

#include <Arduino.h>
#include <Wire.h>
#include <U8g2lib.h>
#include <RTClib.h>
#include <esp_adc_cal.h>

//Definicje pinów zgodnie ze schematem
#define CLK_BMS 18
#define DT_BMS 19
#define CLK_VOLT 32
#define DT_VOLT 33
#define CLK_TIME 13
#define DT_TIME 15
#define BUTTON_PIN 26 // Pin przycisku enkodera
#define ENCODER_BUTTON_PIN 14 // Pin przycisku enkodera
#define ANALOG_OUT 25
#define VP_PIN 36 // VP (ADC0)
#define VN_PIN 39 // VN (ADC3)
#define DIGITAL_OUT 2 // wy dioda
#define DIGITAL_BMS 5 // BMS dioda
#define DIGITAL_EV 17 //EV dioda

// Zmienne dla enkoderów
volatile int counter_bms = 0;
volatile int counter_volt = 0;
volatile int index_time = 0;

float bms_value = 0.0;
float volt_value = 0.0;

int values_time[] = {5, 15, 30, 45, 60};

int lastStateCLK_BMS = LOW;
int lastStateCLK_VOLT = LOW;
int lastStateCLK_TIME = LOW;


// Zmienne obsługi przycisku
bool buttonState = HIGH; // Aktualny stan przycisku
bool lastButtonState = HIGH; // Poprzedni stan przycisku
unsigned long lastDebounceTime = 0; // Czas ostatniego odczytu przycisku
const unsigned long debounceDelay = 50; // Opóźnienie dla eliminacji drgań styków

// Zmienne obsługi przycisku
bool buttonState1 = HIGH; // Aktualny stan przycisku
bool lastButtonState1 = HIGH; // Poprzedni stan przycisku
unsigned long lastDebounceTime1 = 0; // Czas ostatniego odczytu przycisku
const unsigned long debounceDelay1 = 50; // Opóźnienie dla eliminacji drgań styków


// OLED
U8G2_SH1106_128X64_NONAME_F_HW_I2C u8g2(U8G2_R0, /* reset=*/ U8X8_PIN_NONE);

// RTC
RTC_DS1307 rtc; // Obiekt RTC

// Tryb pracy
enum Mode { AUTOMATIC, MANUAL };
Mode currentMode = AUTOMATIC; // Domyślny tryb

// Tryby źródeł wartości
enum ValueSource { BMS_INPUT, BMS_ENCODER };
ValueSource currentValueSource = BMS_INPUT; // Domyślny tryb


// Kalibracja ADC
const float VREFS[] = {0.0, 1.1, 2.2, 3.3}; // Napięcia referencyjne (V)
const uint32_t ADC_POINTS[] = {0, 1370, 2740, 4095}; // Wartości ADC dla kalibracji

// Eksponencjalne wygładzanie
float filteredVP = 0.0;
float filteredVN = 0.0;
const float ALPHA = 0.1; // Współczynnik wygładzania

float targetValvePosition = 8.0; // Celowa wartość otwarcia zaworu (80%)
float outputVoltage = 10.0;      // Początkowa wartość wyjściowa (maksymalna)
unsigned long lastAdjustmentTime = 0;

static unsigned long previousMillis = 0; // Czas ostatniego wykonania kodu opóźnienia
const unsigned long interval = 100;      // Interwał czasowy (100 ms)

// Korekta offsetu dla dolnych, średnich i górnych wartości
float applyOffsetCorrection(float voltage) {

  if (voltage > 0.0 && voltage <= 2.7) {
    return voltage + 0.1; // Korekta dla dolnego zakresu

  } else if (voltage > 2.7 && voltage <= 3.0) {
    return voltage - 0.05; // Korekta dla górnego zakresu
  }
  else if (voltage > 3.0 && voltage <= 3.05) {
    return voltage - 0.1; // Korekta dla górnego zakresu
  }
   else if (voltage > 3.05 && voltage <= 3.1) {
    return voltage - 0.2; // Korekta dla górnego zakresu
  }
   else if (voltage > 3.1 && voltage <= 3.14){
    return voltage - 0.3; // Korekta dla górnego zakresu
  }
  return voltage; // Bez korekcji poza zakresem
}

// Funkcja interpolacji kawałkowej
float interpolateVoltage(uint32_t adc_reading) {
  for (int i = 0; i < 3; i++) {
    if (adc_reading >= ADC_POINTS[i] && adc_reading <= ADC_POINTS[i + 1]) {
      // Oblicz współczynnik skalowania w bieżącym zakresie
      float slope = (VREFS[i + 1] - VREFS[i]) / (ADC_POINTS[i + 1] - ADC_POINTS[i]);
      return VREFS[i] + slope * (adc_reading - ADC_POINTS[i]);
    }
  }
  // Zabezpieczenie przed wartościami poza zakresem
  return adc_reading < ADC_POINTS[0] ? VREFS[0] : VREFS[3];
}

float applyExponentialSmoothing(float currentValue, float previousValue, float alpha) {
  return alpha * currentValue + (1 - alpha) * previousValue;
}

// Funkcja zmiany trybu
void changeMode() {
  currentMode = (currentMode == AUTOMATIC) ? MANUAL : AUTOMATIC;
}


//Funkcja obsługi enkodera BMS
void IRAM_ATTR handleEncoderBMS() {
  int currentStateCLK = digitalRead(CLK_BMS);
  if (currentStateCLK != lastStateCLK_BMS && currentStateCLK == HIGH) {
    if (digitalRead(DT_BMS) != currentStateCLK) {
      if (counter_bms < 100) counter_bms++;
    } else {
      if (counter_bms > 0) counter_bms--;
    }
    bms_value = counter_bms * 0.1;
  }
  lastStateCLK_BMS = currentStateCLK;
}

//Funkcja obsługi enkodera VOLT
void IRAM_ATTR handleEncoderVOLT() {
  int currentStateCLK = digitalRead(CLK_VOLT);
  if (currentStateCLK != lastStateCLK_VOLT && currentStateCLK == HIGH) {
    if (digitalRead(DT_VOLT) != currentStateCLK) {
      if (counter_volt < 100) counter_volt++;
    } else {
      if (counter_volt > 0) counter_volt--;
    }
    volt_value = counter_volt * 0.1;
  }
  lastStateCLK_VOLT = currentStateCLK;
}

//Funkcja obsługi enkodera TIME
void IRAM_ATTR handleEncoderTIME() {
  int currentStateCLK = digitalRead(CLK_TIME);
  if (currentStateCLK != lastStateCLK_TIME && currentStateCLK == HIGH) {
    if (digitalRead(DT_TIME) != currentStateCLK) {
      if (index_time < (sizeof(values_time) / sizeof(values_time[0]) - 1)) {
        index_time++;
      }
    } else {
      if (index_time > 0) {
        index_time--;
      }
    }
  }
  lastStateCLK_TIME = currentStateCLK;
}

void setup() {
  Serial.begin(115200);
  Wire.begin(21, 22); // SDA, SCL
  u8g2.begin();

  if (!rtc.begin()) {
    Serial.println("RTC nie znaleziono!");
    while (1);
  }

  if (!rtc.isrunning()) {
    rtc.adjust(DateTime(F(__DATE__), F(__TIME__))); // Ustawienie czasu na podstawie kompilacji
  }

  u8g2.clearBuffer();
  u8g2.setFont(u8g2_font_ncenB08_tr);
  u8g2.drawStr(0, 10, "Start programu!");
  u8g2.sendBuffer();
  delay(2000);

  pinMode(CLK_BMS, INPUT_PULLUP);
  pinMode(DT_BMS, INPUT_PULLUP);
  pinMode(CLK_VOLT, INPUT_PULLUP);
  pinMode(DT_VOLT, INPUT_PULLUP);
  pinMode(CLK_TIME, INPUT_PULLUP);
  pinMode(DT_TIME, INPUT_PULLUP);
  pinMode(BUTTON_PIN, INPUT_PULLUP);
  pinMode(ANALOG_OUT, OUTPUT);
  pinMode(ENCODER_BUTTON_PIN, INPUT_PULLUP); // Konfiguracja przycisku enkodera
  pinMode(DIGITAL_OUT, OUTPUT);
  pinMode(DIGITAL_BMS, OUTPUT);
  pinMode(DIGITAL_EV, OUTPUT);


  lastStateCLK_BMS = digitalRead(CLK_BMS);
  lastStateCLK_VOLT = digitalRead(CLK_VOLT);
  lastStateCLK_TIME = digitalRead(CLK_TIME);

  attachInterrupt(digitalPinToInterrupt(CLK_BMS), handleEncoderBMS, CHANGE);
  attachInterrupt(digitalPinToInterrupt(CLK_VOLT), handleEncoderVOLT, CHANGE);
  attachInterrupt(digitalPinToInterrupt(CLK_TIME), handleEncoderTIME, CHANGE);
}

void loop() {
    static unsigned long lastAdjustmentTime = 0; // Ostatni czas regulacji
    static bool firstRun = true; // Flaga dla pierwszego uruchomienia
    static bool lastButtonState = HIGH; // Poprzedni stan przycisku enkodera
    bool currentButtonState = digitalRead(ENCODER_BUTTON_PIN); // Odczyt stanu przycisku enkodera

    // Obsługa przycisku enkodera do zmiany trybu
    if (currentButtonState == LOW && lastButtonState == HIGH) { // Wciśnięcie przycisku
        delay(debounceDelay); // Eliminacja drgań styków
        if (digitalRead(ENCODER_BUTTON_PIN) == LOW) { // Potwierdzenie stanu
            currentValueSource = static_cast<ValueSource>((currentValueSource + 1) % 2); // Przełączenie trybu
        }
    }
    lastButtonState = currentButtonState;

    // Obsługa przycisku z eliminacją drgań styków
    bool reading = digitalRead(BUTTON_PIN);
    if (reading != lastButtonState1) {
        lastDebounceTime1 = millis();
    }
    if ((millis() - lastDebounceTime1) > debounceDelay1) {
        if (reading != buttonState1) {
            buttonState1 = reading;
            if (buttonState1 == LOW) { // Aktywacja na zboczu opadającym
                changeMode();
            }
        }
    }
    lastButtonState1 = reading;

    // Początkowy stan (100% mocy pompy)
    if (firstRun) {
        outputVoltage = 10.0; // Ustawienie na maksymalną moc
        firstRun = false;
    }

    // Odczyt wartości VP i VN
    uint32_t adcVP = analogRead(VP_PIN);
    uint32_t adcVN = analogRead(VN_PIN);

    // Interpolacja i korekta napięć
    float vpVoltage = applyOffsetCorrection(interpolateVoltage(adcVP));
    float vnVoltage = applyOffsetCorrection(interpolateVoltage(adcVN));

    // Wygładzanie sygnałów
    filteredVP = applyExponentialSmoothing(vpVoltage, filteredVP, ALPHA);
    filteredVN = applyExponentialSmoothing(vnVoltage, filteredVN, ALPHA);

    // Skalowanie napięć do 0-10 V
    float scaledVP = filteredVP * (10.0 / 3.3);
    float scaledVN = filteredVN * (10.0 / 3.3);

    // Ustawienie czasu regulacji na podstawie enkodera
    int adjustmentInterval = values_time[index_time];

    // Logika regulacji w trybie automatycznym
    if (currentMode == AUTOMATIC) {
        unsigned long currentMillis = millis();
        if (currentMillis - lastAdjustmentTime >= adjustmentInterval * 1000) { // Sprawdzenie interwału czasu
                // Priorytet sygnału BMS
                if (scaledVN >= 0.1 && currentValueSource == BMS_INPUT) {
                  outputVoltage = scaledVN; // Korzystaj z wartości BMS_INPUT, jeśli VN > 0
              } else if (bms_value >= 0.1 && currentValueSource == BMS_ENCODER) {
                  outputVoltage = bms_value; // W przeciwnym razie użyj enkodera  
                }
             else {
      
                 if (scaledVP < outputVoltage) { // Jeśli położenie zaworu mniejsze niż zadane
                    outputVoltage = max(outputVoltage - 0.1, 0.0); // Zmniejsz napięcie
                } else if (scaledVP > outputVoltage) { // Jeśli położenie zaworu większe niż zadane
                    outputVoltage = min(outputVoltage + 0.1, 10.0); // Zwiększ napięcie
                }
                else if(scaledVP == outputVoltage){
                  outputVoltage = scaledVP;
                }
            }
            lastAdjustmentTime = currentMillis; // Aktualizacja czasu regulacji
        
        }
        // Aktualizacja PWM w trybie automatycznym
        int pwmValue1 = (outputVoltage / 10.0) * 255;
        analogWrite(ANALOG_OUT, pwmValue1);
    }

    if (currentMode == MANUAL) {
        // Wyjście PWM w trybie ręcznym
        int pwmValue = (volt_value / 10.0) * 255;
        analogWrite(ANALOG_OUT, pwmValue);
    }

    // Obsługa diod
    digitalWrite(DIGITAL_OUT, (outputVoltage > 0.1) ? HIGH : LOW); // Sygnalizacja wyjścia
    digitalWrite(DIGITAL_BMS, (scaledVN > 0.1) ? HIGH : LOW);      // Sygnalizacja BMS
    digitalWrite(DIGITAL_EV, (scaledVP > 0.1) ? HIGH : LOW);       // Sygnalizacja EV

    // Wyświetlanie na OLED
    DateTime now = rtc.now();
    u8g2.clearBuffer();
    u8g2.setCursor(0, 10);
    u8g2.printf("Czas: %02d:%02d:%02d", now.hour(), now.minute(), now.second());
    u8g2.setCursor(0, 20);
    u8g2.printf("Tryb: %s", currentMode == AUTOMATIC ? "AUTO" : "MANUAL");
    u8g2.setCursor(0, 30);
    u8g2.printf("EV: %.1fV BMS: %.1fV", scaledVP, scaledVN);
// Wyświetlanie wartości wyjściowej w zależności od trybu
if (currentMode == AUTOMATIC) {
    u8g2.setCursor(0, 40);
    u8g2.printf("Output: %.1fV", outputVoltage); // Wyjście w trybie automatycznym
} else if (currentMode == MANUAL) {
    u8g2.setCursor(0, 40);
    u8g2.printf("Output: %.1fV", volt_value); // Wyjście w trybie manualnym
}
    u8g2.setCursor(0, 50);
    u8g2.printf("BMS_IN: %s", currentValueSource == BMS_INPUT ? "BMS_INPUT" : "BMS_ENC");
    u8g2.setCursor(0, 60);
    u8g2.printf("N: T=%ds B=%.1fV V=%.1fV", adjustmentInterval, bms_value, volt_value);
    u8g2.sendBuffer();


// Obsługa opóźnienia 100 ms bez blokowania
unsigned long currentMillis = millis();
if (currentMillis - previousMillis >= interval) {
    previousMillis = currentMillis;

}

}

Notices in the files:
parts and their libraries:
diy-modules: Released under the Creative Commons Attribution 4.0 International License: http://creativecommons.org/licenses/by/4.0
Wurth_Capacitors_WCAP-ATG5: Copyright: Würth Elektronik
